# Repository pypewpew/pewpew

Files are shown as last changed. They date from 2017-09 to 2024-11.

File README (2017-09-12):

PewPew Lite FeatherWing is a shield for the Adafruit Feather boards that lets
your easily make simple games with CircuitPython.

* Project page: https://hackaday.io/project/21578-pewpew-featherwing
* Documentation: http://pewpew.readthedocs.io/
* Store: https://www.tindie.com/products/deshipu/pewpew-lite-featherwing/

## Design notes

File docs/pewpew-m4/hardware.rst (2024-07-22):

Hardware
********

Specifications
==============

+---------------------------------------------------------+
| Specification                                           |
+==============+==========================================+
| Display      | 160x128 color TFT                        |
+--------------+------------------------------------------+
| Input        | 7 buttons                                |
+--------------+------------------------------------------+
| Sound        | 7mm buzzer                               |
+--------------+------------------------------------------+
| Interface    | Micro USB                                |
+--------------+------------------------------------------+
| Controller   | SAMD51 ARM Cortex M4                     |
+--------------+------------------------------------------+
| Battery      | 2xAAA 1.5V (not included, optional)      |
+--------------+------------------------------------------+

Open Development
================

This hardware is developed in the open, and all the designs and related
materials are publicly available under a permissive license. You are free
to inspect how it is build, build your own, improve and extend the design,
and even sell your own versions.

The designs are available in the
`project's repository <https://github.com/pypewpew/pewpew-m4-v8>`_.

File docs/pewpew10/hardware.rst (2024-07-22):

Hardware
********

PewPew Standalone v10.2
=======================

PewPew Standalone is a handheld device, it doesn't require any additional
hardware, except for two 1.5V AAA batteries.

+---------------------------------------------------------+
| Specification                                           |
+==============+==========================================+
| Display      | 8×8 red LED matrix                       |
+--------------+------------------------------------------+
| Input        | 6 buttons                                |
+--------------+------------------------------------------+
| Sound        | no sound                                 |
+--------------+------------------------------------------+
| Interface    | 12-pin connector at the back             |
+--------------+------------------------------------------+
| Controller   | Atmel SAMD21                             |
+--------------+------------------------------------------+
| Battery      | 2 x AAA 1.5V alkaline (not included)     |
+--------------+------------------------------------------+

The device includes a display, six buttons, on-off switch, USB port and a
battery holder. The batteries are required for operation, it can't be powered
from the USB port. There is also a 12-pin connector on the back of the device
that can be used for connecting other electronic devices.

.. _12-pin-connector:

The 12-pin Connector
====================

+-------+----------+----------------------------------------------+
| Label | Name     | Function                                     |
+=======+==========+==============================================+
| ``R`` | Reset    | Ground this pin to perform hard reset.       |
+-------+----------+----------------------------------------------+
| ``-`` | GND      | Negative power and ground. There are 2 pins. |
+-------+----------+----------------------------------------------+
| ``1`` | board.P1 | DigitalIO, SWC, SPI-MISO/MOSI, PWM           |
+-------+----------+----------------------------------------------+
| ``2`` | board.P2 | DigitalIO, SWD, SPI-SCK, PWM                 |
+-------+----------+----------------------------------------------+
| ``3`` | board.P3 | DigitalIO, I2C-SDA, SPI-MISO/MOSI, PWM       |
+-------+----------+----------------------------------------------+
| ``4`` | board.P4 | DigitalIO, I2C-SCL, SPI-SCK, PWM             |
+-------+----------+----------------------------------------------+
| ``5`` | board.P5 | DigitalIO, ADC, DAC, PWM, TouchIO            |
+-------+----------+----------------------------------------------+
| ``6`` | board.P6 | DigitalIO, ADC, TouchIO                      |
+-------+----------+----------------------------------------------+
| ``7`` | board.P7 | DigitalIO, SPI-MISO/MOSI, UART, TouchIO      |
+-------+----------+----------------------------------------------+
| ``+`` | VCC      | Positive 3V power. There are 2 pins.         |
+-------+----------+----------------------------------------------+

You can insert a male header into the holes at the back of the device and plug
it into a breadboard to easily gain access to the pins.

Updating the Firmware
=====================

1. Download a ``.uf2`` file from `https://circuitpython.org/board/pewpew10/ <https://circuitpython.org/board/pewpew10/>`_.
2. Connect the PewPew to your computer using a USB cable. It appears as a disk
   named *CIRCUITPY*.
3. Back up all your files, as the update might delete them.
4. "Eject" or "safely remove" the ``CIRCUITPY`` disk.
5. Connect the ``R`` and ``-`` pins on the :ref:`12-pin connector
   <12-pin-connector>` twice in short succession, like a double-click. Seen from
   the front, these are the two rightmost pins. If you added a male pin header,
   this is easily done by touching any metal part to the two pins. The PewPew
   display should go black and a disk named *TRINKETBOOT* should appear.
6. If the *CIRCUITPY* disk reappears instead and the PewPew display shows the
   scrolling menu (or whatever else you installed as ``main.py``), try the
   double-click again, it can take a few tries to get the rhythm right.
7. Copy the downloaded ``.uf2`` file to the *TRINKETBOOT* disk. When it’s done,
   which should take no longer than a few seconds, *TRINKETBOOT* disappears,
   *CIRCUITPY* reappears, and your PewPew is now running the new CircuitPython
   version.
8. If needed, copy all your files back. Also, if you upgraded to a new major
   version, you will need to replace any ``.mpy`` files you have on your device,
   with ones compiled for the new version.

Open Development
================

This hardware is developed in the open, and all the designs and related
materials are publicly available under a permissive license. You are free to
inspect how it is build, build your own, improve and extend the design, and
even sell your own versions.

The designs are available in the
`project's repository <https://github.com/pypewpew>`_.

Buy a Kit
=========

If you want to buy a kit that you only need to solder, you can
find one at `Tindie <https://www.tindie.com/products/deshipu/small-pewpew-standalone/>`_.

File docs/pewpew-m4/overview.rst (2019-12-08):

PewPew M4
*********

PewPew M4 is a CircuitPython graphical handheld game console.

.. toctree::
    :maxdepth: 2

    hardware.rst
    assembly.rst

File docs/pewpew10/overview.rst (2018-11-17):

PewPew 10.2
===========

PewPew 10.2 is a standalone version of the PewPew device, designed specifically
to be cheap and simple to use in workshop settings. You only need two AAA
batteries and a micro-USB cable (with a computer to plug it into) to start
using it.

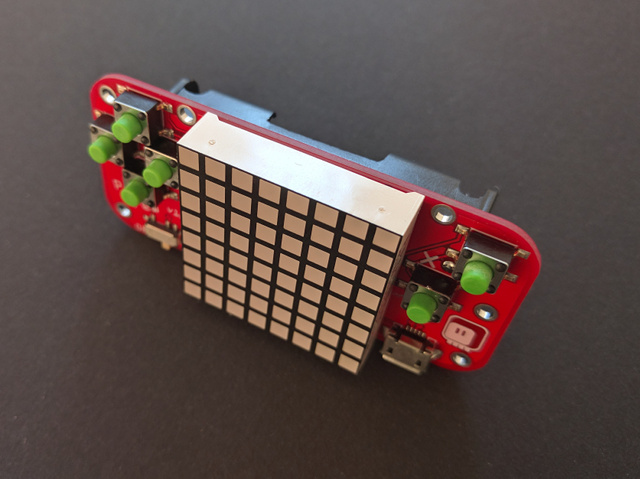
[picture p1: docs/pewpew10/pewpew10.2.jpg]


.. toctree::
    :maxdepth: 2

    hardware.rst
    assembly.rst

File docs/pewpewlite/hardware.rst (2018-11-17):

Hardware
********

PewPew Lite FeatherWing
=======================

PewPew Lite is a shield for the Adafruit Feather series of development boards
(a FeatherWing, as they call them). You put it on top of one of their boards,
and then program that board (preferably in CircuitPython) to create games and
other interactive programs.

+---------------------------------------------------------+
| Specification                                           |
+==============+==========================================+
| Display      | 8×8 4-color LED matrix                   |
+--------------+------------------------------------------+
| Input        | 6 buttons                                |
+--------------+------------------------------------------+
| Sound        | no sound                                 |
+--------------+------------------------------------------+
| Interface    | 2-wire I²C at address 0x70               |
+--------------+------------------------------------------+
| Controller   | Holtek HT16K33                           |
+--------------+------------------------------------------+
| Battery      | Optional 3.7V 100mAh LiPO (not included) |
+--------------+------------------------------------------+

The shield contains six buttons and an eight-by-eight bi-color LED display,
capable of displaying four different colors (black, green, red and yellow). It
also includes a HT16K33 chip that handles the display and the buttons, so that
you can focus on just writing the code for your game. Optionally, you can add a
LiPO battery to it, to make the whole thing into a portable handheld game
console. The shield includes a power switch for that battery.

Open Development
================

This hardware is developed in the open, and all the designs and related
materials are publicly available under a permissive license. You are free
to inspect how it is build, build your own, improve and extend the design,
and even sell your own versions.

The designs are available in the
`project's repository <https://github.com/deshipu/pewpew>`_.

Buy a Kit
=========

If you want to buy a complete kit that doesn't require soldering, you can find
one at `Tindie <https://www.tindie.com/products/deshipu/pewpew-lite-featherwing/>`_.

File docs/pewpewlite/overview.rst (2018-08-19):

PewPew Lite FeatherWing
***********************

PewPew Lite is a FeatherWing that you can use with any of the Adafruit Feather
development boards. It's exactly the size of all FeatherWings, with a green-red
display 2cm on a side, six clicky buttons and a switch for an optional battery.

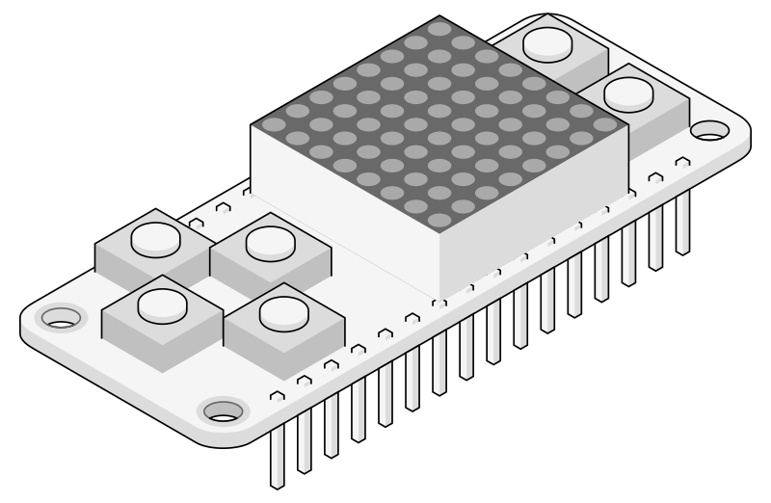
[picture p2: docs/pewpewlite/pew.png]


.. toctree::
    :maxdepth: 2

    hardware.rst
    assembly.rst

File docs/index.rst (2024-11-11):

Welcome to PewPew Documentation
*******************************

PewPew is a family of handheld devices that make learning to write simple
games with Python easy, and also let you tinker with electronics.

They all have a small 8×8 display and six buttons, and they all use the same
"pew" library for accessing them. However, they differ in size, price and
features available.

.. toctree::
    :maxdepth: 2

    pew.rst
    tutorial.rst
    tutorial-sokoban.rst
    tutorial-mine.rst
    pewmulator.rst
    devices.rst
    components.rst
    community.rst

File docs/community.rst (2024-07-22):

Community
*********

If you would like to talk with other users of the device, exchange ideas, seek
help, share the games you made or simply just see what is happening in the
project, you can `subscribe to the mailing list <https://mail.python.org/mailman3/lists/pewpew.python.org/>`_.

There are also some users active at `CircuitPython
Discord <https://discordapp.com/channels/327254708534116352/327298996332658690>`_
channel, if you prefer a more interactive chat.

All the code and design files for the project can be found in the `pewpew-game GitHub repository <https://github.com/pypewpew/>`_.

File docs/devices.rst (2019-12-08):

PewPew Devices
**************

There are several different PewPew devices out there, and a number of further
devices can be made compatible with PewPew by using the right libraries. You
can even build your own device!

.. toctree::
    :maxdepth: 2

    pewpewlite/overview.rst
    pewpew10/overview.rst
    pewpew-m4/overview.rst

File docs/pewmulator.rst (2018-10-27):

Pewmulator
**********

Pewmulator is an emulator for the PewPew library that lets you play the games
writen for the PewPew devices on your computer. It comes in the form of a
Python 3 library that uses PyGame under the hood to implement all necessary
parts of the PewPew library.

Note that the code is then being executed with Python 3 and not CircuitPython,
so there may be some differences. The most obvious difference is the amount of
RAM memory available --- so if you write a game in Pewmulator, chances are it
won't run on PewPew because of lack of memory.

You can get the library from the `github repository
<https://github.com/pewpew-game/pewmulator>`_. Just place the ``pew.py`` file
alongside the code of your game, and run your game with Python 3.

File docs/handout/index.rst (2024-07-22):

:orphan:

.. raw:: latex

   \pagenumbering{gobble}
   \setcounter{secnumdepth}{0}

Handout
=======

.. toctree::
   :maxdepth: 2

   page1header
   ../pew
   page1footer
   ../components/led
   page2footer
   ../components/potentiometer
   page3footer
   ../components/dotstar
   page4footer
   ../components/speaker
   page5footer
   ../components/accelerometer
   page6footer

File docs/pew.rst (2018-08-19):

PewPew Library Reference
************************

.. module:: pew

.. function:: init()

    Initialize the module.

    This function switches the display on and performs some basic setup.

.. function:: brightness(level)

    Set the brightness of the display, from 0 (minimum) to 15 (maximum). On
    devices that don't support varying the brightness this does nothing.

.. function:: show(pix)

    Show the provided image on the display, starting at the top left corner.
    You will want to call this once for every frame.

.. function:: keys()

    Return a number telling which keys (or buttons) have been pressed since the
    last check.  The number can then be filtered with the ``&`` operator and
    the ``K_X``, ``K_DOWN``, ``K_LEFT``, ``K_RIGHT``, ``K_UP``, and ``K_O``
    constants to see whether any of the keys was pressed.

.. function:: tick(delay)

    Wait until ``delay`` seconds have passed since the last call to this
    function. You can call it every frame to ensure a constant frame rate.

.. class:: Pix(width=8, height=8, buffer=None)

    Pix represents a drawing surface, ``width`` pixels wide and ``height``
    pixels high.

    If no ``buffer`` is specified for storing the data, a suitable one will
    be automatically created.

    .. classmethod:: from_iter(cls, lines)

        Creates a new Pix and initialzes its contents by iterating over
        ``lines`` and then over individual pixels in each line. All the lines
        have to be at least as long as the first one.

    .. classmethod:: from_text(cls, text, color=None, background=0, colors=None)

        Creates a new Pix and renders the specified text on it. It is exactly
        the size needed to fit the specified text. Newlines and other control
        characters are rendered as spaces.

        If ``color`` is not specified, it will use yellow and red for the
        letters by default. Otherwise it will use the specified color, with
        ``background`` color as the background.

        Alternatively, ``colors`` may be specified as a 4-tuple of colors,
        and then the ``color`` and ``background`` arguments are ignored, and
        the four specified colors are used for rendering the text.

    .. method:: pixel(self, x, y, color=None)

        If ``color`` is specified, sets the pixel at location ``x``, ``y`` to
        that color. If not, returns the color of the pixel at that location.

        If the location is out of bounds of the drawing surface, returns 0.

    .. method:: box(self, color, x=0, y=0, width=self.width, height=self.height)

        Draws a filled box with the specified ``color`` with its top left
        corner at the specified location and of the specified size. If no
        location and size are specified, fills the whole drawing surface.

    .. method:: blit(self, source, dx=0, dy=0, x=0, y=0, width=None, height=None, key=None)

        Copied the ``source`` drawing surface onto this surface at location
        specified with ``dx`` and ``dy``.

        If ``x``, ``y``, ``widht`` and ``height`` are specified, only copies
        that fragment of the ``source`` image, otherwise copies it whole.

        If ``key`` color is specified, that color is considered transparent
        on the source image, and is not copied onto this drawing surface.

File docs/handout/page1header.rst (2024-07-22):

.. rubric:: Radomir Dopieralski ‹vispew@sheep.art.pl›      Christian Walther ‹cwalther@gmx.ch›

.. rubric:: https://pewpew.rtfd.io

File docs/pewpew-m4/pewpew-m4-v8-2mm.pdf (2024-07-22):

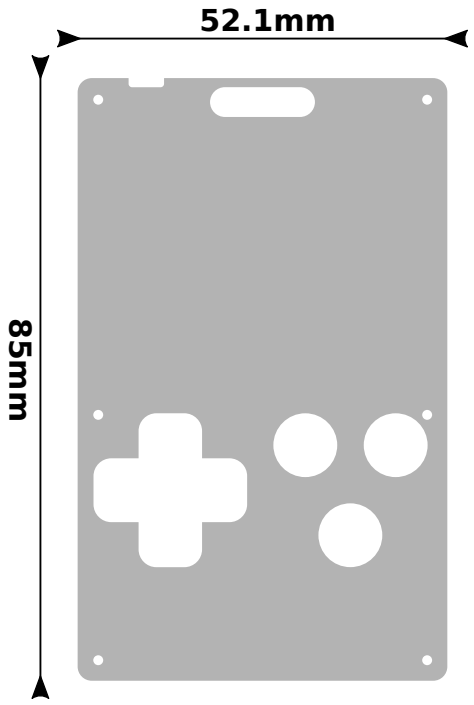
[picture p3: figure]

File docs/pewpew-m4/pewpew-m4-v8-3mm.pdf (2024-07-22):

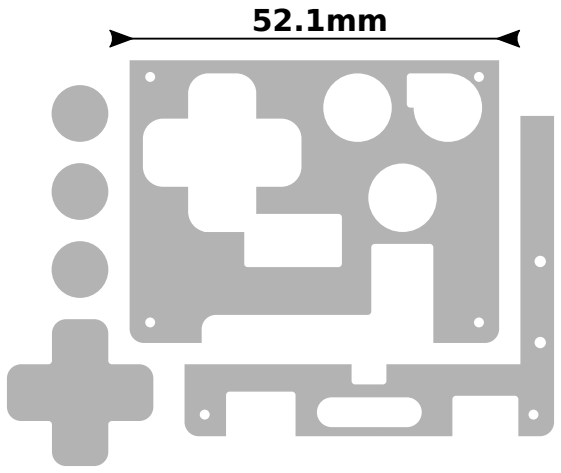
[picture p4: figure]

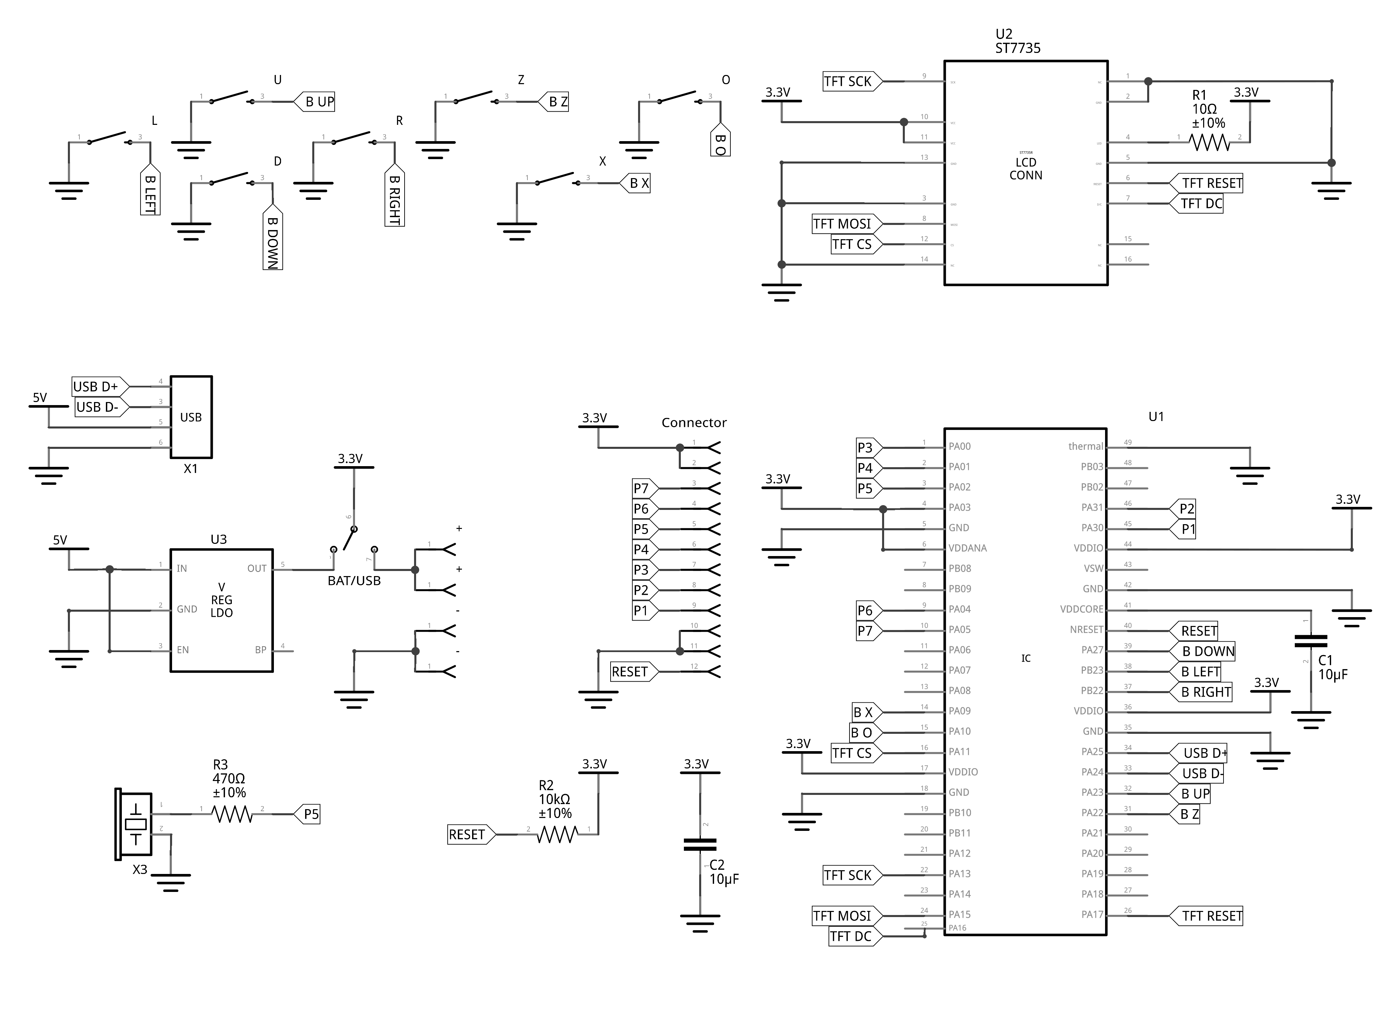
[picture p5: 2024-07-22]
docs/pewpew-m4/pewpew-m4-v8-schematic.png

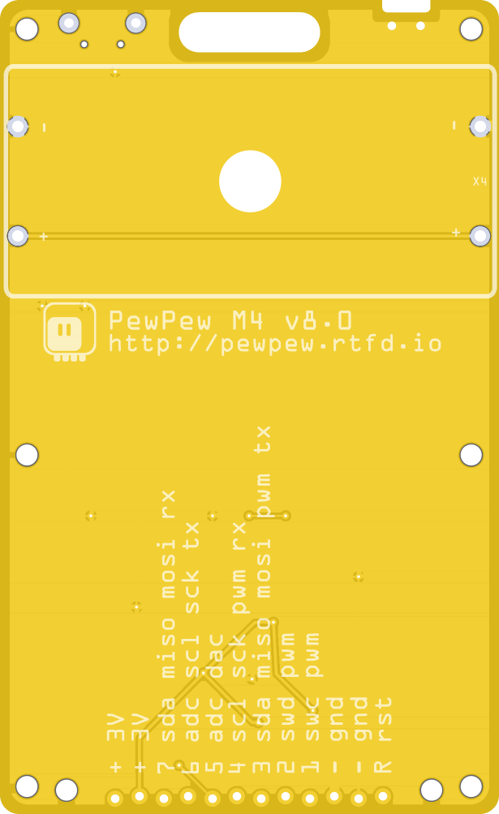
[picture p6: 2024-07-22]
docs/pewpew-m4/pewpew-m4-v8-pcb-bottom.png

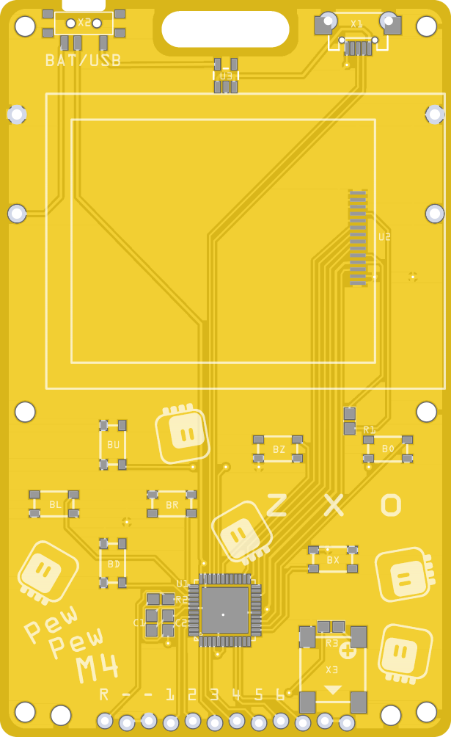
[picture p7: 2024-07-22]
docs/pewpew-m4/pewpew-m4-v8-pcb-top.png

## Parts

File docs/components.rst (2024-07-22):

Connecting Electronics
======================

This section contains some examples to get you started with enhancing your PewPew with various external electronic components.

.. toctree::
   :maxdepth: 2

   components/led
   components/potentiometer
   components/dotstar
   components/speaker
   components/accelerometer

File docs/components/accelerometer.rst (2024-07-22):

Accelerometer
-------------



An accelerometer senses gravity and acceleration using microscopic mechanical parts that are integrated on a silicon chip. It can be used to detect orientation, motion, and gestures like tapping.

The LIS3DH is a low-cost model of accelerometer among many others by different manufacturers. It is a digital device that talks to the microcontroller bidirectionally using a protocol named I²C (*I*\ nter *I*\ ntegrated *C*\ ircuit). I²C uses two signal lines, SDA (*s*\ erial *da*\ ta) and SCL (*s*\ erial *cl*\ ock), plus a common ground. Additionally, I²C requires two resistors (*pull-up resistors*) between each of the signal lines and the positive supply voltage (VCC), this is already done on our LIS3DH breakout board. Multiple devices can be connected to the same I²C bus, the microcontroller can identify them by their address.

To avoid having to remember the raw commands that the microcontroller needs to send over I²C to talk to the accelerometer (they are documented in the `data sheet <https://learn.adafruit.com/adafruit-lis3dh-triple-axis-accelerometer-breakout/downloads>`_ of the part), we use a library that encapsulates that knowledge and abstracts away the specifics of the device. Check the documentation at https://learn.adafruit.com/adafruit-lis3dh-triple-axis-accelerometer-breakout and https://circuitpython.readthedocs.io/projects/lis3dh to learn more about its capabilities, such as tap and double-tap detection. Some of them require additional wiring.

Libraries required: https://github.com/adafruit/Adafruit_CircuitPython_LIS3DH and https://github.com/adafruit/Adafruit_CircuitPython_BusDevice

::

   >>> import board
   >>> import adafruit_lis3dh
   >>> a = adafruit_lis3dh.LIS3DH_I2C(board.I2C(), address=0x1d)
   >>> a.acceleration
   acceleration(x=-0.0862066, y=0.019157, z=9.73177)
   # in m/s^2
   
   >>> import pew
   >>> import math
   >>> pew.init()
   >>> screen = pew.Pix()
   >>> while True:
   ...     x, y, z = a.acceleration
   ...     screen.box(0)
   ...     screen.pixel(4 + math.floor(0.3*x), 3 - math.floor(0.3*y), 3)
   ...     pew.show(screen)
   ...

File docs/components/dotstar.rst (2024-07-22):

Addressable LED Strip
---------------------



These strips can be several meters long and contain hundreds of LEDs, each of them individually controllable. Each of the addressable LED packages contains three LEDs (red, green, blue; some also have a fourth white one) and a controller chip with communication input and output pins. They are daisy-chained on the strip so that the output of one goes to the input of the next. The input of the first one is connected to the microcontroller, which sends out a stream of color values. The first LED takes the first set of them and keeps it for itself, then passes all the rest through to the next one, and so on, until the last LED on the strip only receives the last set of values left for it.

Addressable LEDs exist in two common varieties, “Neopixels” (WS2812B, SK6812), which have one communication line (data), and “Dotstars” (APA102, SK9822), which have two (clock and data). They are all intended for 5 V, but the Dotstars used here happen to work acceptably on 3 V.

Powering 3 addressable LEDs from the PewPew battery or USB supply works, but for longer strips you need a separate power supply (unless you keep very few LEDs on at any time). Each LED can use up to 60 mA (3*20) – multiplied by a large number, this quickly overwhelms small power supplies.

Arrows on the strip indicate the data flow direction – make sure you connect the controller to the input end of the strip. The 5V and GND supply lines run through the whole strip and connect all LEDs in parallel, these can be connected on either end (or even both).

Libraries required: https://github.com/adafruit/Adafruit_CircuitPython_Pixelbuf and https://github.com/adafruit/Adafruit_CircuitPython_Dotstar

::

   >>> import adafruit_dotstar
   >>> import board
   >>> d = adafruit_dotstar.DotStar(board.P2, board.P1, 3, pixel_order=adafruit_dotstar.RBG)
   >>> d
   [[0, 0, 0, 1.0], [0, 0, 0, 1.0], [0, 0, 0, 1.0]]
   # [R (0-255), G (0-255), B (0-255), brightness (0.0-1.0 in steps of 1/31)]
   >>> d[0] = 0x100000
   >>> d[0] = 0x001000
   >>> d[0] = 0x000010
   >>> d[0] = (20, 10, 0)
   >>> d.fill(0)
   >>> import time
   >>> import math
   >>> d.brightness = 0.2
   >>> while True:
   ...     for i in range(3):
   ...         d[i] = [int(255*math.sin(time.monotonic() - 0.5*j + 2.1*i)**12) for j in range(3)]
   ... 
   >>> d.deinit()
   # send raw data using a lower-level interface without the adafruit_dotstar library
   >>> import busio
   >>> spi = busio.SPI(board.P2, MOSI=board.P1)
   >>> spi.try_lock()
   True
   >>> spi.write(b'\x00\x00\x00\x00\xff\x33\x00\x00\xff\x00\x33\x00\xff\x00\x00\x33\xff')
   >>> spi.unlock()
   >>> spi.deinit()

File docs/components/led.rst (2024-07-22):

.. _leds:

Light-Emitting Diodes (LEDs)
----------------------------



.. raw:: latex

   \vspace{4mm}

An LED must be connected in the right orientation: it has a negative lead (cathode) and a positive lead (anode). The cathode is usally marked by being shorter and by a flat part on the rim of the transparent body. Nothing breaks it you insert it the wrong way, it just doesn’t light up.

An LED needs a resistor connected in series, otherwise too much current flows through it and destroys it. It doesn’t matter which way around and on which side of the LED the resistor is placed.

An RGB LED is simply three individual LEDs in the same case, with their cathodes (or anodes) connected together to the longest lead, and the anodes (or cathodes) exposed individually. We use a larger resistance on the green LED because otherwise it is much brighter than the other two, this brings them closer to making white together.

To turn LEDs on and off, we can use any of the PewPew pins as digital outputs.

::

   >>> import board
   >>> import digitalio
   >>> led = digitalio.DigitalInOut(board.P1)
   >>> led.direction = digitalio.Direction.OUTPUT
   >>> led.value = 1
   >>> led.value = 0

Pulse-Width Modulation (PWM)
----------------------------

To dim an LED, we can make use of the microcontroller’s ability to blink an output very quickly, with a fixed frequency, but a variable duration of the “on” part of the period. This is called *pulse-width modulation* (PWM) and is easier for a microcontroller to do than outputting a continuously variable voltage. The ratio of the “on” part to the whole period is called *duty cycle* and is specified as an integer from 0 (always off) to 65535 (always on).

::

   >>> import board
   >>> import pwmio
   >>> r = pwmio.PWMOut(board.P1)
   >>> g = pwmio.PWMOut(board.P3)
   >>> b = pwmio.PWMOut(board.P4)
   >>> r.duty_cycle = 0
   >>> r.duty_cycle = 100
   >>> r.duty_cycle = 10000
   >>> r.duty_cycle = 65535
   >>> import time
   >>> import math
   >>> while True:
   ...     r.duty_cycle = int(65535*(0.5 + 0.5*math.sin(time.monotonic())))
   ...     g.duty_cycle = int(65535*(0.5 + 0.5*math.sin(time.monotonic() - 2.1)))
   ...     b.duty_cycle = int(65535*(0.5 + 0.5*math.sin(time.monotonic() - 4.2)))
   ... 
   #   ^ delete the indenting spaces and press return to end the block
   # press ctrl-C to exit from the infinite loop

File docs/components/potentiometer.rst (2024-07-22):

Potentiometer
-------------



A potentiometer is an adjustable resistor. As its schematic symbol illustrates, it consists of a track of resistive material on which a wiper can slide. The left and right end of the track are connected to the outer pins of the part, the wiper to the middle pin. When the wiper is moved to the left end, the resistance between the left and middle pins is approximately zero. As the wiper is moved to the right, it continuously increases until it reaches the full value when the wiper is at the right end. Conversely, the resistance between the middle and right pins decreases.

When the left and right ends of the track are connected to ground (0V) and +3V (which makes a small current flow through it), the potentiometer acts as a variable *voltage divider*: the middle pin smoothly moves from 0V to 3V as the wiper is moved from left to right.

We can measure this voltage using an analog-to-digital converter (ADC) contained in the microcontroller. On the PewPew, ADCs are available on pins 5, 6, and 7. They linearly convert a voltage between zero and the full supply voltage into an integer between 0 and 65535.

An analog joystick is a combination of two potentiometers.

Light-Dependent Resistor (LDR)
------------------------------



The resistance of an LDR decreases when light shines onto it.

We can combine it to a voltage divider with a fixed resistor and measure the resulting variable voltage using an ADC.

.. raw:: latex

   ~\\ \\

::

   >>> import board
   >>> import analogio
   >>> adc = analogio.AnalogIn(board.P5)
   # potentiometer turned to the left
   >>> adc.value
   48
   # potentiometer turned to the right
   >>> adc.value
   65520
   >>> import pew
   >>> pew.init()
   >>> screen = pew.Pix()
   >>> while True:
   ...     screen.blit(screen, 0, 0, 1, 0, 7, 8)
   ...     screen.box(0, 7, 0, 1, 8)
   ...     screen.pixel(7, 7 - (adc.value >> 13), 3)
   ...     pew.show(screen)
   ...     pew.tick(0.1)
   ... 
   #   ^ delete the indenting spaces and press return to end the block
   # press ctrl-C to exit from the infinite loop

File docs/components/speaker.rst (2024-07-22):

Piezo Speaker
-------------



A piezo speaker (also called *passive buzzer*) converts electricity into sound using a crystal that expands and contracts when placed in an electric field. It is not suitable for high-quality music, but good for simple beeps, and uses very little power. It doesn’t matter which way you connect it.

The PewPew 10 lacks most of the advanced sound generation capabilities of CircuitPython because they didn’t fit in the small flash memory of the microcontroller, but we can generate simple square waves using the pulse-width modulation facility (described on the :ref:`leds` page).

(There is a digital-to-analog converter (DAC) on pin 5 that can be used with the ``analogio`` module, but feeding it new values regularly enough for sound is hard without support from the firmware.)

.. raw:: latex

   ~\\

::

   >>> import board
   >>> import pwmio
   >>> p = pwmio.PWMOut(board.P4, variable_frequency=True)
   >>> p.duty_cycle = 32768
   # initial frequency is 500 Hz
   >>> p.frequency = 250
   >>> p.frequency = 1000
   >>> p.duty_cycle = 0

   >>> import time
   >>> def play(tune):
   ...     p.duty_cycle = 32768
   ...     for f, d in tune:
   ...         p.frequency = f
   ...         time.sleep(d)
   ...     p.duty_cycle = 0
   ... 
   >>> play(((440, 0.2), (550, 0.1), (587, 0.1), (660, 0.1)))

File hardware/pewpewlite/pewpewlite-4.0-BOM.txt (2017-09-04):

8x8 1.9mm common-cathode bi-color matrix 788AHG     $1.50   1x  $1.50
HT16K33 28SOP                                       $0.60   1x  $0.60
39kΩ 0805 resistor                                  $0.004  6x  $0.024
4.7kΩ 0805 resistor                                 $0.004  2x  $0.008
SPDT slide switch MK12C02                           $0.10   1x  $0.10
Tact switch 6x6x4.5mm                               $0.02   6x  $0.12
2.54mm male pin header                              $0.05   1x  $0.05
Custom PCB 50.6x22.7mm                              $1.00   1x  $1.00
Solder, flux, etc.                                  $0.168  1x  $0.168
----------------------------------------------------------------------
                                                        Total:  $3.50

Note: prices are for a batch of 10 pieces.

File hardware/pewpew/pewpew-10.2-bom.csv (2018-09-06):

Part/Designator | Manufacture Part Number/Description | Quantity | Remarks/Links
U1 | ATSAMD21E18A-MU | 1 | microcontroller: https://www.mouser.ch/ProductDetail/556-ATSAMD21E18A-MU
C1,C2 | 1uF 0805 capacitor | 2
ON/OFF | MK12C02 | 1 | switch: https://www.aliexpress.com/item/10PCS-Lot-MP3-Toggle-Switch-MK12C02-7P-12608-Micro-Switch-Miniature-Toggle-MP3-Key-Button/32812362709.html
X2 | 10118193-0001LF | 1 | microusb socket: https://www.aliexpress.com/item/20PCS-LOT-MicroUSB-socket-MK5P-Mike-5P-MINIUSB-USB-5-pin-female/32874709816.html
O,X,up,down,left,right | SMD Tact Switch 6*6*6mm Green | 6 | https://www.aliexpress.com/item/4-Pins-SMT-Mini-Hand-Touch-Switch-SMD-Tact-Switch-6-6-6mm-White-Green-Orange/32698050818.html
X1 | 1088BS 8x8 Red 3mm Square LED Matrix | 1 | Leave unsoldered, https://www.aliexpress.com/item/FREE-SHIPPING-10PCS-x-3MM-8X8-RED-32-32mm-Square-LED-Dot-Matrix-Digital-Tube-Module/32756487745.html
+/- | 2xAAA battery holder | 1 | Leave unsoldered, https://www.aliexpress.com/item/7Pcs-Black-Red-2-Wire-Cable-Connectors-2x-AAA-Battery-Box-Case-Holder/32871718687.html

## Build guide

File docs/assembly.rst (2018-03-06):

Assembly and Setup
******************

The PewPew FeatherWing comes without the pin headers and LED matrix attached,
so that some simple soldering is required before using it.

Basic Assembly
==============

The simplest way to assemble the PewPew board is to use an `Adafruit Feather
<https://www.adafruit.com/category/946>`_ board that supports CircuitPython (the
`Feather M0 Express <https://www.adafruit.com/product/3403>`_ works great for
this) with female pin headers, and to solder the male pin headers onto the
PewPew FeatherWing. Afterwards, insert the LED Matrix into place, solder its
pins from the bottom, and trim them with wire cutters.

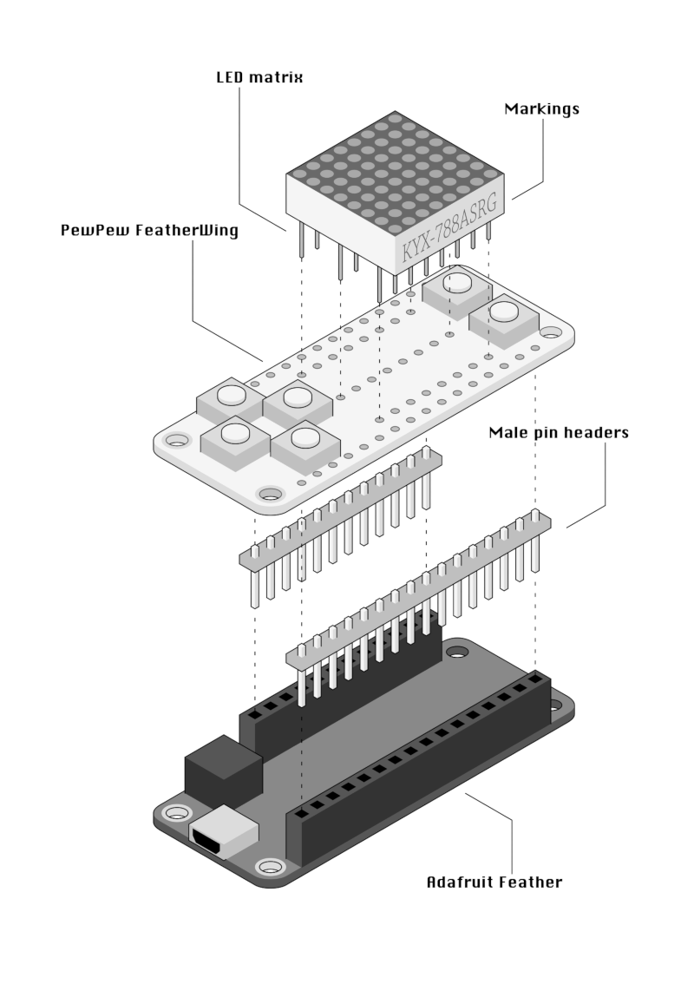
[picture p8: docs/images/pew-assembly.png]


Make sure to insert the LED Matrix in correct orientation -- with the markings
in the same direction as the "down" button. Otherwise the colors will be wrong,
and the image will be flipped.

Note that you should solder the pin headers first, and then solder the LED
matrix. Trying to do it in the opposite order may lead to damaging the matrix
with your soldering iron.

.. note:: The Adafruit Feather board is not included in the kit.

Making it Flatter
=================

The basic assembly is fine, but it's good 2cm thick. You can make the whole
thing much thinner by applying a number of tricks. First, use the `short female
pin headers <https://www.adafruit.com/product/2940>`_ for the Adafruit Feather.
Second, move the plastic on your male pin headers to the end of the header,
insert the header from the top, and try it with the Feather to see how long the
pins need to be. Then solder them, and trim the parts sticking out from the top
with wire cutters. This way the PewPew FeatherWing can sit right on top of the
battery plug of the Feather.

.. note:: Note that the short female headers are not included in the kit.

Optional Battery
================

To make the PewPew even more portable, you can add a small LiPO battery (`the
100mAh batteries <https://www.adafruit.com/product/1570>`_ are about the right
size). The FeatherWing even has a power switch built-in that you can use. Just
solder the battery leads to the two holes marked "+" for the red wire, and "-"
for the black wire. Be very careful to not short the battery wires while you
are doing that. Then you can use two-sided tape to stick the battery on the
underside of the FeatherWing, sandwiching it between the two boards. You may
need to add some electric tape to prevent the metal body of the battery from
shorting things on the boards.

.. note:: Note that the battery is not included in the kit.

Software Setup
==============

All the example programs are written using CircuitPython, so you will need to
get that running on your Feather board. Fortunately Adafruit provides a lot of
tutorials about how to do it. Some of the boards (like the M0 Express) even
come with CircuitPython already loaded on them. Please see
 `this guide <https://learn.adafruit.com/welcome-to-circuitpython/installing-circuitpython>`_.

Once you have CircuitPython running on the board, you need to copy the
``pew.mpy`` file to it. That's the main library that contains all the functions
needed to use the PewPew hardware.

In addition, you need to copy your program onto the board. You have to name it
``main.py`` for it to be started automatically on power-up. Later on we will
see how we can use a menu program that will let you choose what to run (you
have to rename the ``menu.py`` to ``main.py`` to have it run at start).

You can get all the files from the `project's repository
<https://github.com/deshipu/pewpew>`_, and the compiled files are available
from the `releases page <https://github.com/pewpew-game/pewpew/releases>`_.

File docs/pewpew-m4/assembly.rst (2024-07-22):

Assembly and Setup
******************

Electronics
===========

If you bought a kit, you will receive this part already assembled and programmed.

Schematic
---------

This is the schematic of the device.



Printed Circuit Board
---------------------

A printed circuit board is necessary for assembling the electronic part of the
console. You can find the gerber files in the project's repository.





If you need to make modifications to the PCB designs, the Fritzing file is also
available in the project's repository.

Bill of Materials
-----------------

You will need the following components:

+--------------------+-----------------------------------+--------+---------------------------------------------------------------------------------+
|Part/Designator     |Manufacture Part Number/Description|Quantity|Remarks/Links                                                                    |
+====================+===================================+========+=================================================================================+
|U1                  |ATSAMD51G19A-MU                    |1       |`Mouser <https://www.mouser.ch/ProductDetail/556-ATSAMD51G19AMU>`_               |
+--------------------+-----------------------------------+--------+---------------------------------------------------------------------------------+
|U2                  |ST7735R 1.8inch TFT                |1       |https://www.aliexpress.com/item/32818686437.html                                 |
+--------------------+-----------------------------------+--------+---------------------------------------------------------------------------------+
|U3                  |AP2112K-3.3TRG1 ldo                |1       |                                                                                 |
+--------------------+-----------------------------------+--------+---------------------------------------------------------------------------------+
|C1 C2               |10uF 0805 capacitor 3V             |2       |                                                                                 |
+--------------------+-----------------------------------+--------+---------------------------------------------------------------------------------+
|R1                  |10Ohm 0805 resistor                |1       |                                                                                 |
+--------------------+-----------------------------------+--------+---------------------------------------------------------------------------------+
|R2                  |10kOhm 0805 resistor               |1       |                                                                                 |
+--------------------+-----------------------------------+--------+---------------------------------------------------------------------------------+
|R3                  |470Ohm 0805 resistor               |1       |                                                                                 |
+--------------------+-----------------------------------+--------+---------------------------------------------------------------------------------+
|X1                  |10118193-0001LF microusb socket    |1       |https://www.aliexpress.com/item/32874709816.html                                 |
+--------------------+-----------------------------------+--------+---------------------------------------------------------------------------------+
|X2                  |MK12C02 switch                     |1       |https://www.aliexpress.com/item/32812362709.html                                 |
+--------------------+-----------------------------------+--------+---------------------------------------------------------------------------------+
|X3                  |HYG7525                            |1       |https://www.aliexpress.com/item/1707004675.html                                  |
+--------------------+-----------------------------------+--------+---------------------------------------------------------------------------------+
|X4                  |2xAAA battery holder               |1       |https://www.aliexpress.com/item/32921198766.html                                 |
+--------------------+-----------------------------------+--------+---------------------------------------------------------------------------------+
|BU BD BL BR BZ BX BO|SKRPABE010 switch 1.57N            |7       |https://www.aliexpress.com/item/4000424101435.html                               |
+--------------------+-----------------------------------+--------+---------------------------------------------------------------------------------+
|                    |two-sided tape                     |1.5cm   |for attaching the battery holder https://www.aliexpress.com/item/33030272723.html|
+--------------------+-----------------------------------+--------+---------------------------------------------------------------------------------+

The positions of the components are marked on the PCB's silkscreen, and there
is also a pick-and-place file included with the gerbers.

Please make sure to use the correct set of holes for the battery holder,
depending on the polarity of the particular model you have. If you need to use
the holes on the side of the display connector, it's best to solder the battery
holder first, and the display later.

Bootloader
----------

You will find the UF2 bootloader binary and sources in the project's
repository.  In order to flash it to the chip on the PCB, you will need an
SWD-capable programmer, such as JLink.

Connect your programmer to the 12-pin connector at the bottom as follows:

+----------+------+
|Programmer|Device|
+==========+======+
|SWDCLK    | 1    |
+----------+------+
|SWDIO     | 2    |
+----------+------+
|RST       | R    |
+----------+------+
|VCC       | ``+``|
+----------+------+
|GND       | ``-``|
+----------+------+

While programming, the device needs to be powered either from battery, from
USB, or with 3.3V through the ``+`` and ``-`` pins.

If programming from the command line, use the following commands::

    JLinkExe -if SWD -device ATSAMD51G19A -speed 4000kHz
    J-Link> connect
    J-Link> erase
    J-Link> loadbin pewpew-m4-v8-bootloader.bin 0
    J-Link> g
    J-Link> qc

After this, a ``PEWBOOT`` disk should become visible over USB. The UF2 files
can be copied to that disk to flash them on the device.  To force the device
into a bootloader mode again, the ``R`` pin needs to be shorted with the ``-``
twice.

Firmware
--------

The CircuitPython firmware can be downloaded form the `official CircuitPython
downloads page <http://circuitpython.org/downloads>`_. The UF2 file just needs
to be copied over USB to the ``PEWBOOT`` disk.

Case
====

The case consists of two layers of acrylic parts, held together with six
screws, and four button caps, attached to the switches with pieces of two-sided
tape or glue. The whole assembly is shown below.



Acrylic Layers
--------------

The acrylic parts are laser-cut from 2mm clear and 3mm translucent sheets.





It's possible to cut more than one set of parts from a single sheet, so you may
want to modify the provided designs. Please also note that the design files
include dimensions, which should be ignored by the cutter.

Bill of Materials
------------------

+-------------------------------------+--------+------------------------------------------------+
|Description                          |Quantity|Remarks/Links                                   |
+=====================================+========+================================================+
|M1.8 6mm flat-head self-tapping screw|6       |https://www.aliexpress.com/item/32976344389.html|
+-------------------------------------+--------+------------------------------------------------+
|2mm clear transparent acrylic parts  |1       |see pewpew-m4-v8-2mm.svg                        |
+-------------------------------------+--------+------------------------------------------------+
|3mm orange translucent acrylic parts |1       |see pewpew-m4-v8-3mm.svg                        |
+-------------------------------------+--------+------------------------------------------------+

Project Reposiotory
===================

All the design files can be found in the `project's repository
<https://github.com/pewpew-game/pewpew-m4-v8>`_.

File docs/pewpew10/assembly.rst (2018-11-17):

Assembly
********

Unless you are participating in a workshop, the device comes unassembled. There
are three parts: the printed circuit board with the buttons and the
electronics, the display, and the battery holder. To assemble it you will need
a soldering iron, wire cutters, solder and two-sided tape. You will also need
two AAA 1.5V batteries, a micro-USB cable and a computer with a working USB
port.

Display
-------

You start the assembly by attaching and soldering the display. Insert the
provided LED matrix into the 16 holes in the middle of the printed circuit
board, making sure that the side of the matrix with text on it faces right,
towards the two fire buttons. You may need to straighten the pins a little if
they bent during the transport.

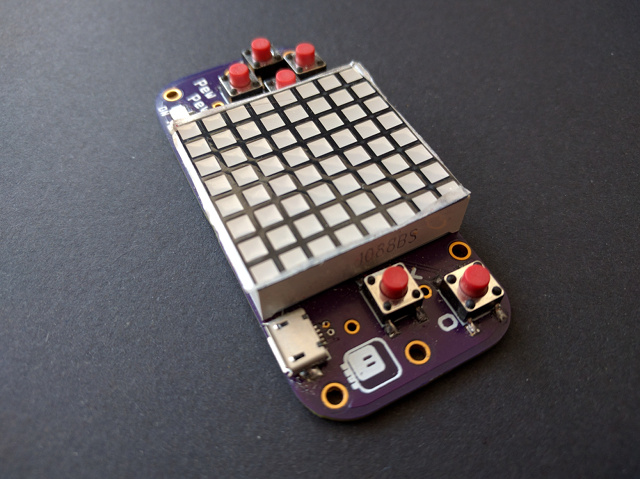
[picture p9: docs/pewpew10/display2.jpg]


.. warning:: If you solder the display in the wrong orientation, it will not
    work correctly. Please make sure the orientation is correct before you
    start soldering.

Once the matrix is inserted, flip the device up-side-down, make sure that the
display aligns flush with the sides (there is a little wiggle room), and solder
each of the pins. To do that, touch the tip of a hot soldering iron to the pin
and the ring around the hole at the same time, wait a second for them to become
hot, and then touch them with the solder wire, melting enough solder to fill
the hole.

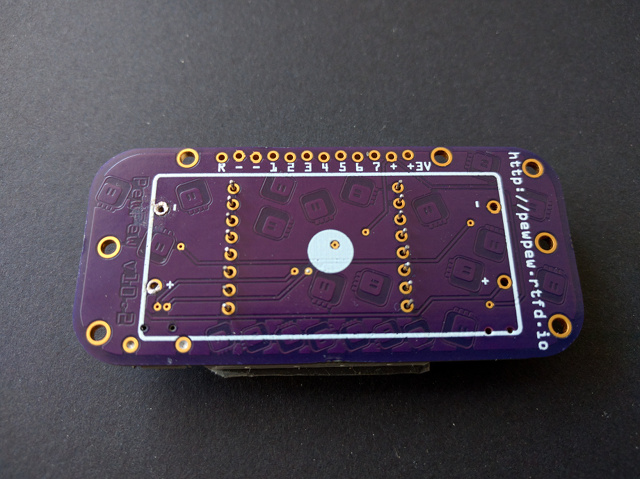
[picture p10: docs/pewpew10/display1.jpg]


.. note:: If you are new to soldering, you can find soldering tutorials on the
    Internet.

Once all 16 pins of the matrix are soldered, use the wire cutters to cut them
flush with the circuit board.

Battery
-------

The next step is connecting and attaching the battery holder. First, make sure
that the wires of the battery holder go through the holes in the plastic that
are furthest apart. If they go through the holes that are close together, you
will need to move them back, and thread them through the correct holes. Once
you have done that, cut both wires to about 1cm length and remove the
insulation from them with the wire cutters (please don't use your teeth). Twist
the strands of each of the wire, so that they are easier to move through the
holes in the circuit board. Next, place two-sided tape on the battery holder,
and attach it to the circuit board so that the two wires go through the holes
marked + and - (make sure the red wire goes to +, and the black one to -).
There are two sets of such holes, pick the correct one depending on what order
the wires come out of your battery holder.

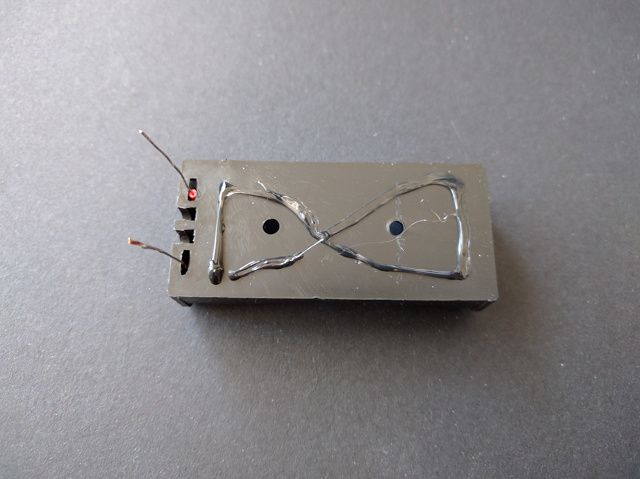
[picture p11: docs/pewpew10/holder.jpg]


.. warning:: It is very important to pay attention to the battery polarity, as
    this device doesn't have any kind of reverse polarity protection, and
    coonnecting the batteries in reverse will damage it.

Flip the device to the top side, and use the soldering iron to solder the two
wires sticking out of the holes in the circuit board. Be careful to not touch
the plastic of the buttons with your iron, as it will melt. Finally, cut the
excess wires with your wire cutters. Your device is ready.

Insert two AAA 1.5V batteries into the battery holder, switch it on, and you
should see text "snake" scrolling on the display.

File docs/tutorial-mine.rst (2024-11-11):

Mine Tutorial
*************

We will make a game inspired by titles such as Dig Dug and Boulder Dash, where
the player controls a miner, who digs tunnel in a mine filled with boulders and
treasure. The goal is to collect all the treasure without being crushed by a
boulder.

We will start with creating and displaying the map of the mine:

.. code-block:: python

    import pew

    pew.init()
    world = pew.Pix.from_iter([
        [1, 1, 1, 1, 1, 1, 1, 1],
        [1, 1, 1, 1, 1, 1, 1, 1],
        [1, 1, 2, 1, 2, 1, 1, 1],
        [1, 1, 2, 1, 3, 1, 1, 1],
        [1, 1, 1, 1, 1, 1, 2, 1],
        [1, 1, 1, 1, 1, 2, 3, 2],
        [1, 3, 1, 1, 1, 1, 2, 1],
        [1, 1, 1, 1, 1, 1, 1, 1],
    ])
    delay = 1/6
    end = False

    while not end:
        pew.show(world)
        pew.tick(delay)

In the above code, we initialize the ``pew`` library, create a bitmap
to hold the map of the world, and then, in an infinite loop, display it
and wait for the next frame.

Next we want to display the miner:

.. code-block:: python
    :emphasize-lines: 15-17,23,26

    import pew

    pew.init()
    world = pew.Pix.from_iter([
        [1, 1, 1, 1, 1, 1, 1, 1],
        [1, 1, 1, 1, 1, 1, 1, 1],
        [1, 1, 2, 1, 2, 1, 1, 1],
        [1, 1, 2, 1, 3, 1, 1, 1],
        [1, 1, 1, 1, 1, 1, 2, 1],
        [1, 1, 1, 1, 1, 2, 3, 2],
        [1, 3, 1, 1, 1, 1, 2, 1],
        [1, 1, 1, 1, 1, 1, 1, 1],
    ])
    x = 0
    y = 0
    blink = True
    delay = 1/6
    end = False

    while not end:
        world.pixel(x, y, 3 if blink else 0)
        pew.show(world)
        pew.tick(delay)
        blink = not blink

We define global variables ``x`` and ``y`` to hold the position of the
miner, and ``blink`` to track what color we should display. Then we
just color the pixel at that position depending on the state of
``blink``, and flip it to the other state.

Next, we will let the player move the miner:

.. code-block:: python
    :emphasize-lines: 23-42

    import pew

    pew.init()
    world = pew.Pix.from_iter([
        [1, 1, 1, 1, 1, 1, 1, 1],
        [1, 1, 1, 1, 1, 1, 1, 1],
        [1, 1, 2, 1, 2, 1, 1, 1],
        [1, 1, 2, 1, 3, 1, 1, 1],
        [1, 1, 1, 1, 1, 1, 2, 1],
        [1, 1, 1, 1, 1, 2, 3, 2],
        [1, 3, 1, 1, 1, 1, 2, 1],
        [1, 1, 1, 1, 1, 1, 1, 1],
    ])
    x = 0
    y = 0
    blink = True
    delay = 1/6
    end = False

    while not end:
        world.pixel(x, y, 4)
        buttons = pew.keys()
        while pew.keys():
            pew.tick(delay)
        dx = 0
        dy = 0
        if buttons & pew.K_UP:
            dy = -1
        elif buttons & pew.K_DOWN:
            dy = 1
        elif buttons & pew.K_LEFT:
            dx = -1
        elif buttons & pew.K_RIGHT:
            dx = 1
        if (0 <= x + dx <= 7 and 0 <= y + dy <= 7 and
                world.pixel(x + dx, y + dy) != 2):
            world.pixel(x, y, 0)
            x += dx
            y += dy
            world.pixel(x, y, 4)
        world.pixel(x, y, 3 if blink else 0)
        pew.show(world)
        pew.tick(delay)
        blink = not blink

We will paint the position of the miner with a non-existng color 4
temporarily, so that it will be easier for us later to check various
conditions. Later we overwrite it with the blinking color anyways, so
this is never visible.

Then we read the state of the buttons, wait for all buttons to be released,
and figure out the direction in which we want to move depending on which
buttons are pressed.

Then we check if the movement wouldn't take us outside the screen, horizontally and vertically, and if there isn't a boulder in the way. If everything is fine, we draw a tunnel where the miner was, and move them to the new position.

Next, we will add pushing of boulders:

.. code-block:: python
    :emphasize-lines: 43-49

    import pew

    pew.init()
    world = pew.Pix.from_iter([
        [1, 1, 1, 1, 1, 1, 1, 1],
        [1, 1, 1, 1, 1, 1, 1, 1],
        [1, 1, 2, 1, 2, 1, 1, 1],
        [1, 1, 2, 1, 3, 1, 1, 1],
        [1, 1, 1, 1, 1, 1, 2, 1],
        [1, 1, 1, 1, 1, 2, 3, 2],
        [1, 3, 1, 1, 1, 1, 2, 1],
        [1, 1, 1, 1, 1, 1, 1, 1],
    ])
    x = 0
    y = 0
    blink = True
    delay = 1/6
    end = False

    while not end:
        world.pixel(x, y, 4)
        buttons = pew.keys()
        while pew.keys():
            pew.tick(delay)
        dx = 0
        dy = 0
        if buttons & pew.K_UP:
            dy = -1
        elif buttons & pew.K_DOWN:
            dy = 1
        elif buttons & pew.K_LEFT:
            dx = -1
        elif buttons & pew.K_RIGHT:
            dx = 1
        if (0 <= x + dx <= 7 and 0 <= y + dy <= 7 and
                world.pixel(x + dx, y + dy) != 2):
            world.pixel(x, y, 0)
            x += dx
            y += dy
            world.pixel(x, y, 4)
        elif (dy == 0 and 1 <= x + dx <= 6 and
                world.pixel(x + 2 * dx, y + 2 * dy) == 0):
            world.pixel(x, y, 0)
            x += dx
            y += dy
            world.pixel(x, y, 4)
            world.pixel(x + dx, y + dy, 2)
        world.pixel(x, y, 3 if blink else 0)
        pew.show(world)
        pew.tick(delay)
        blink = not blink

We check that the movement is horizontal, that we are not pushing the boulder
outside the screen, and that there is an empty space behind the boulder. Then
we move both the miner and the boulder.

Finally, we need to add gravity for the boulders, so that they fall down when
there is nothing under them.

.. code-block:: python
    :emphasize-lines: 50-57

    import pew

    pew.init()
    world = pew.Pix.from_iter([
        [1, 1, 1, 1, 1, 1, 1, 1],
        [1, 1, 1, 1, 1, 1, 1, 1],
        [1, 1, 2, 1, 2, 1, 1, 1],
        [1, 1, 2, 1, 3, 1, 1, 1],
        [1, 1, 1, 1, 1, 1, 2, 1],
        [1, 1, 1, 1, 1, 2, 3, 2],
        [1, 3, 1, 1, 1, 1, 2, 1],
        [1, 1, 1, 1, 1, 1, 1, 1],
    ])
    x = 0
    y = 0
    blink = True
    delay = 1/6
    end = False

    while not end:
        world.pixel(x, y, 4)
        buttons = pew.keys()
        while pew.keys():
            pew.tick(delay)
        dx = 0
        dy = 0
        if buttons & pew.K_UP:
            dy = -1
        elif buttons & pew.K_DOWN:
            dy = 1
        elif buttons & pew.K_LEFT:
            dx = -1
        elif buttons & pew.K_RIGHT:
            dx = 1
        if (0 <= x + dx <= 7 and 0 <= y + dy <= 7 and
                world.pixel(x + dx, y + dy) != 2):
            world.pixel(x, y, 0)
            x += dx
            y += dy
            world.pixel(x, y, 4)
        elif (dy == 0 and 1 <= x + dx <= 6 and
                world.pixel(x + 2 * dx, y + 2 * dy) == 0):
            world.pixel(x, y, 0)
            x += dx
            y += dy
            world.pixel(x, y, 4)
            world.pixel(x + dx, y + dy, 2)
        for row in range(7, -1, -1):
            for col in range(8):
                if world.pixel(col, row) == 2:
                    if world.pixel(col, row + 1) == 0:
                        world.pixel(col, row, 0)
                        world.pixel(col, row + 1, 2)
                        if world.pixel(col, row + 2) == 4:
                            end = True
        world.pixel(x, y, 3 if blink else 0)
        pew.show(world)
        pew.tick(delay)
        blink = not blink

    import supervisor
    supervisor.reload()

We iterate over the whole world map, starting from the bottom row-by-row, and going up. Every time we find a boulder, we check if there is an empty space under it. If there is, we move it into that empty space. Since we are going from the bottom up, we will only do this once every frame, so we can see the boulder falling gradually down when there is more space below it.

In addition, if we hit the miner while falling, we end the game by setting the ``end`` variable to ``True``. We added a reload at the end of the program, to make sure we can play the game from the beginning.

But boulders only falling down is not that interesting, we also want them to slip sideways if they stand on other boulders and there is empty space on the side.

.. code-block:: python
    :emphasize-lines: 58-66

    import pew

    pew.init()
    world = pew.Pix.from_iter([
        [1, 1, 1, 1, 1, 1, 1, 1],
        [1, 1, 1, 1, 1, 1, 1, 1],
        [1, 1, 2, 1, 2, 1, 1, 1],
        [1, 1, 2, 1, 3, 1, 1, 1],
        [1, 1, 1, 1, 1, 1, 2, 1],
        [1, 1, 1, 1, 1, 2, 3, 2],
        [1, 3, 1, 1, 1, 1, 2, 1],
        [1, 1, 1, 1, 1, 1, 1, 1],
    ])
    x = 0
    y = 0
    blink = True
    delay = 1/6
    end = False

    while not end:
        world.pixel(x, y, 4)
        buttons = pew.keys()
        while pew.keys():
            pew.tick(delay)
        dx = 0
        dy = 0
        if buttons & pew.K_UP:
            dy = -1
        elif buttons & pew.K_DOWN:
            dy = 1
        elif buttons & pew.K_LEFT:
            dx = -1
        elif buttons & pew.K_RIGHT:
            dx = 1
        if (0 <= x + dx <= 7 and 0 <= y + dy <= 7 and
                world.pixel(x + dx, y + dy) != 2):
            world.pixel(x, y, 0)
            x += dx
            y += dy
            world.pixel(x, y, 4)
        elif (dy == 0 and 1 <= x + dx <= 6 and
                world.pixel(x + 2 * dx, y + 2 * dy) == 0):
            world.pixel(x, y, 0)
            x += dx
            y += dy
            world.pixel(x, y, 4)
            world.pixel(x + dx, y + dy, 2)
        for row in range(7, -1, -1):
            for col in range(8):
                if world.pixel(col, row) == 2:
                    if world.pixel(col, row + 1) == 0:
                        world.pixel(col, row, 0)
                        world.pixel(col, row + 1, 2)
                        if world.pixel(col, row + 2) == 4:
                            end = True
                    elif world.pixel(col, row + 1) in {2, 3}:
                        if (world.pixel(col + 1, row) == 0 and
                           world.pixel(col + 1, row + 1) == 0):
                                world.pixel(col, row, 0)
                                world.pixel(col + 1, row, 2)
                        elif (world.pixel(col - 1, row) == 0 and
                           world.pixel(col - 1, row + 1) == 0):
                                world.pixel(col, row, 0)
                                world.pixel(col - 1, row, 2)
        world.pixel(x, y, 3 if blink else 0)
        pew.show(world)
        pew.tick(delay)
        blink = not blink

    import supervisor
    supervisor.reload()

If there is no empty space below a boulder, we check if it's another boulder
or treasure. If it is, we check the two spaces to the left and to the right -- if they are empty, we can move the boulder sideways, and it will fall down in the next frame.

Finally, we need a winning condition. We need to count how many treasures are there left on the map, and end the game when there are none.

.. code-block:: python
    :emphasize-lines: 50,53-55,70-71

    import pew

    pew.init()
    world = pew.Pix.from_iter([
        [1, 1, 1, 1, 1, 1, 1, 1],
        [1, 1, 1, 1, 1, 1, 1, 1],
        [1, 1, 2, 1, 2, 1, 1, 1],
        [1, 1, 2, 1, 3, 1, 1, 1],
        [1, 1, 1, 1, 1, 1, 2, 1],
        [1, 1, 1, 1, 1, 2, 3, 2],
        [1, 3, 1, 1, 1, 1, 2, 1],
        [1, 1, 1, 1, 1, 1, 1, 1],
    ])
    x = 0
    y = 0
    blink = True
    delay = 1/6
    end = False

    while not end:
        world.pixel(x, y, 4)
        buttons = pew.keys()
        while pew.keys():
            pew.tick(delay)
        dx = 0
        dy = 0
        if buttons & pew.K_UP:
            dy = -1
        elif buttons & pew.K_DOWN:
            dy = 1
        elif buttons & pew.K_LEFT:
            dx = -1
        elif buttons & pew.K_RIGHT:
            dx = 1
        if (0 <= x + dx <= 7 and 0 <= y + dy <= 7 and
                world.pixel(x + dx, y + dy) != 2):
            world.pixel(x, y, 0)
            x += dx
            y += dy
            world.pixel(x, y, 4)
        elif (dy == 0 and 1 <= x + dx <= 6 and
                world.pixel(x + 2 * dx, y + 2 * dy) == 0):
            world.pixel(x, y, 0)
            x += dx
            y += dy
            world.pixel(x, y, 4)
            world.pixel(x + dx, y + dy, 2)
        gems = 0
        for row in range(7, -1, -1):
            for col in range(8):
                if world.pixel(col, row) == 3:
                    gems += 1
                elif world.pixel(col, row) == 2:
                    if world.pixel(col, row + 1) == 0:
                        world.pixel(col, row, 0)
                        world.pixel(col, row + 1, 2)
                        if world.pixel(col, row + 2) == 4:
                            end = True
                    elif world.pixel(col, row + 1) in {2, 3}:
                        if (world.pixel(col + 1, row) == 0 and
                           world.pixel(col + 1, row + 1) == 0):
                                world.pixel(col, row, 0)
                                world.pixel(col + 1, row, 2)
                        elif (world.pixel(col - 1, row) == 0 and
                           world.pixel(col - 1, row + 1) == 0):
                                world.pixel(col, row, 0)
                                world.pixel(col - 1, row, 2)
        if gems == 0:
            end = True
        world.pixel(x, y, 3 if blink else 0)
        pew.show(world)
        pew.tick(delay)
        blink = not blink

    import supervisor
    supervisor.reload()

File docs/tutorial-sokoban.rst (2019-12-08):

Sokoban Tutorial
****************

When looking for simple games to implement on PewPew, it helps to look back to
the times when computers were so young and underpowered, compared to today, that
simple games were all they could run. One of those games is Sokoban. Let’s try
to write a Sokoban for PewPew!

`Sokoban <https://en.wikipedia.org/wiki/Sokoban>`_ is a puzzle game where you
play a warehouse worker who has to push packing crates around until they are
where they are supposed to be, which is indicated by marks on the floor.
Unfortunately, your warehouse is a bit labyrinthine, and you can only push the
crates, not pull them, so you need to plan carefully: if you push a crate into a
corner, you can never get it back out.

As in the :doc:`tutorial`, create a file named *code.py* containing the basic
setup and game loop. Instead of a blank screen, we put the game board on the
screen right away: some walls, indicated by color 1 (dim or green), surrounding
free space of color 0 (black). ::

    import pew

    pew.init()
    screen = pew.Pix.from_iter((
        (1, 1, 1, 1, 1, 1, 1, 1),
        (1, 0, 0, 0, 0, 0, 0, 1),
        (1, 0, 0, 0, 0, 0, 0, 1),
        (1, 0, 0, 0, 0, 0, 0, 1),
        (1, 0, 0, 0, 0, 0, 0, 1),
        (1, 0, 0, 0, 0, 0, 0, 1),
        (1, 0, 0, 0, 0, 0, 0, 1),
        (1, 1, 1, 1, 1, 1, 1, 1),
    ))

    while True:
        keys = pew.keys()

        pew.show(screen)
        pew.tick(1/6)

Let’s add a player character, indicated by a bright pixel, that can be moved
around with the directional keys. We erase the pixel in the old position at the
beginning of the loop by replacing it with 0 (black floor), then move the
position if any keys are pressed, and finally paint it at the new position:

.. code-block:: python
    :emphasize-lines: 5,6,9,11-19

    ...
        (1, 1, 1, 1, 1, 1, 1, 1),
    ))

    x = 4
    y = 1

    while True:
        screen.pixel(x, y, 0)
        keys = pew.keys()
        if keys & pew.K_UP:
            y -= 1
        elif keys & pew.K_DOWN:
            y += 1
        elif keys & pew.K_LEFT:
            x -= 1
        elif keys & pew.K_RIGHT:
            x += 1
        screen.pixel(x, y, 3)
        pew.show(screen)
        pew.tick(1/6)

Note that we use ``elif`` (Python’s shorthand for “else, if”) to check for
different keys, which means that we can only move in one of the four directions
at once. If we used ``if`` for every key, we could move e.g. right and down at
the same time, that is, move diagonally. (We could also move up and down at the
same time, which means not moving at all.) For Sokoban, we don’t want to be able
to move diagonally, only horizontally and vertically, so we use ``elif``.

If you try this, you will notice that the player can move through walls and
outside of the screen, leaving holes in the walls. Let’s fix that.

Instead of moving right away when a key is pressed, we first record in what
direction we want to move in the variables ``dx`` and ``dy`` (the ``d`` stands
for “delta” or “difference”, because this is going to be the difference between
the new and old position). Then we look ahead what is in that direction, the
``target`` pixel, and only move when it is “floor” (0).

.. code-block:: python
    :emphasize-lines: 5,6,8,10,12,14-18

    ...
    while True:
        screen.pixel(x, y, 0)
        keys = pew.keys()
        dx = 0
        dy = 0
        if keys & pew.K_UP:
            dy = -1
        elif keys & pew.K_DOWN:
            dy = 1
        elif keys & pew.K_LEFT:
            dx = -1
        elif keys & pew.K_RIGHT:
            dx = 1
        target = screen.pixel(x+dx, y+dy)
        if target == 0:
            x += dx
            y += dy
        screen.pixel(x, y, 3)
        pew.show(screen)
        pew.tick(1/6)

Now that that works as it should, let’s add the next element, a crate,
represented by a bright pixel (3):

.. code-block:: python
    :emphasize-lines: 6

    ...
        (1, 1, 1, 1, 1, 1, 1, 1),
        (1, 0, 0, 0, 0, 0, 0, 1),
        (1, 0, 0, 0, 0, 0, 0, 1),
        (1, 0, 0, 0, 0, 0, 0, 1),
        (1, 0, 0, 3, 0, 0, 0, 1),
        (1, 0, 0, 0, 0, 0, 0, 1),
        (1, 0, 0, 0, 0, 0, 0, 1),
        (1, 1, 1, 1, 1, 1, 1, 1),
    ...

When a crate is in front of a player wanting to move, it will be pushed away one
pixel further in the same direction, and the player can move:

.. code-block:: python
    :emphasize-lines: 5-8

    ...
        if target == 0:
            x += dx
            y += dy
        elif target == 3:
            screen.pixel(x+dx+dx, y+dy+dy, 3)
            x += dx
            y += dy
        screen.pixel(x, y, 3)
        pew.show(screen)
        pew.tick(1/6)

There is no need to erase the crate at its old position, because it will
immediately be overwritten with the player anyway.

Test it and you will notice that you can push the crate through walls, punching
holes in the walls again. We obviously need to check what’s *behind* the crate
first, before we decide to move it.

.. code-block:: python
    :emphasize-lines: 3,7

    ...
        target = screen.pixel(x+dx, y+dy)
        behind = screen.pixel(x+dx+dx, y+dy+dy)
        if target == 0:
            x += dx
            y += dy
        elif target == 3 and behind == 0:
            screen.pixel(x+dx+dx, y+dy+dy, 3)
            x += dx
            y += dy
    ...

That works, but we now have two bright pixels on the screen, the player and the
crate, and when the player isn’t moving, you can’t tell which is which. We still
have an unused color available that we could use for one of them, 2 (medium
brightness or red), but we’d like to use that for the marks on the floor later.
Instead, let’s make the player blink. That needs another variable to keep track
of what the last state was, which is then reversed after every time the player
is drawn. A natural choice for such a variable with two states is a boolean with
its two values ``True`` and ``False``.

.. code-block:: python
    :emphasize-lines: 4

    ...
    x = 4
    y = 1
    blink = True

    while True:
    ...

.. code-block:: python
    :emphasize-lines: 3,4

    ...
            y += dy
        screen.pixel(x, y, 3 if blink else 2)
        blink = not blink
        pew.show(screen)
        pew.tick(1/6)

Time for the last missing element: the marks on the floor. We represent them by
color 2:

.. code-block:: python
    :emphasize-lines: 6

    ...
        (1, 1, 1, 1, 1, 1, 1, 1),
        (1, 0, 0, 0, 0, 0, 0, 1),
        (1, 0, 0, 0, 0, 0, 0, 1),
        (1, 0, 0, 0, 0, 0, 0, 1),
        (1, 0, 0, 3, 0, 2, 0, 1),
        (1, 0, 0, 0, 0, 0, 0, 1),
        (1, 0, 0, 0, 0, 0, 0, 1),
        (1, 1, 1, 1, 1, 1, 1, 1),
    ...

And the player and crates can move over them just like over bare floor:

.. code-block:: python
    :emphasize-lines: 3,6

    ...
        behind = screen.pixel(x+dx+dx, y+dy+dy)
        if target in {0, 2}:
            x += dx
            y += dy
        elif target == 3 and behind in {0, 2}:
            screen.pixel(x+dx+dx, y+dy+dy, 3)
            x += dx
            y += dy
    ...

Try it out, and you will find the next problem: the mark is erased by either
player or crate moving over it. This is because when overwriting the respective
pixel with 2 or 3 to draw the player, we lose the information whether there was
a mark there, and in the first line of the next loop, we will restore bare floor
(0) even when there should have been a mark (2). We somehow need to preserve
this information.

To solve this, there is a trick we can use. So far, we have always used pixel
values 0–3 for black, dim, medium, bright or black, green, red, orange. These
are all the colors that our hardware can display. But what happens if we use
higher numbers? If you try it, you will find that 4 produces black, 5 produces
dim/green again, 6 medium/red, 7 bright/orange, 8 black, and so on – the pattern
just repeats every four steps. In other words, you can add 4 to a pixel value
without changing its apparent color.

We can use this to our advantage: If we represent a crate-on-bare-floor as 3 and
a crate-on-mark as 7, they will both look the same, but we can still distinguish
them in the code. The same goes for the player: if the pixel blinks between 2
and 3, it’s on bare floor, if it blinks between 6 and 7, it’s on a mark.

For the player, this needs to be applied on the line where we erase the player
and restore the floor (with or without mark), and on the line where we draw the
new player over the previous floor or crate (each with or without mark):

.. code-block:: python
    :emphasize-lines: 3

    ...
    while True:
        screen.pixel(x, y, 0 if screen.pixel(x, y) < 4 else 2)
        keys = pew.keys()
    ...

.. code-block:: python
    :emphasize-lines: 3

    ...
            y += dy
        screen.pixel(x, y, (3 if blink else 2) + (4 if screen.pixel(x, y) in {2, 7} else 0))
        blink = not blink
    ...

For the crate, it needs to be applied on the line where we detect a crate in
front of the player and on the line where we draw the new crate over the
previous floor:

.. code-block:: python
    :emphasize-lines: 5,6

    ...
        if target in {0, 2}:
            x += dx
            y += dy
        elif target in {3, 7} and behind in {0, 2}:
            screen.pixel(x+dx+dx, y+dy+dy, 3 if behind == 0 else 7)
            x += dx
            y += dy
    ...

Test this and check that you can now both walk over the mark and push the crate
over the mark without erasing it. Congratulations – with this, our game
mechanics are now complete! The game still does not detect when all crates are
placed on their marks and therefore the level is solved, though. Let’s add that.

The easiest way of checking that is to count all bare marks: if none of them are
left, the puzzle is solved. So, iterate over all pixels (with an outer loop over
all rows and an inner loop over the pixels of each row) and count up every time
you see a bare mark. If the count remains 0, break out of the top-level ``while
True`` loop, at which point the program ends because there’s no more code after
the loop. It’s important to do this before we draw the player, who might stand
on a mark and thereby hide it from the counting otherwise.

.. code-block:: python
    :emphasize-lines: 6-12

    ...
        elif target in {3, 7} and behind in {0, 2}:
            screen.pixel(x+dx+dx, y+dy+dy, 3 if behind == 0 else 7)
            x += dx
            y += dy
        count = 0
        for b in range(8):
            for a in range(8):
                if screen.pixel(a, b) == 2:
                    count += 1
        if count == 0:
            break
        screen.pixel(x, y, (3 if blink else 2) + (4 if screen.pixel(x, y) in {2, 7} else 0))
        blink = not blink
        pew.show(screen)
        pew.tick(1/6)

You can test this, but testing it with only one crate is not a very general
test, so add another one, and a mark for it.

.. code-block:: python
    :emphasize-lines: 4,7

    ...
        (1, 1, 1, 1, 1, 1, 1, 1),
        (1, 0, 0, 0, 0, 0, 0, 1),
        (1, 0, 3, 0, 0, 0, 0, 1),
        (1, 0, 0, 0, 0, 0, 0, 1),
        (1, 0, 0, 3, 0, 2, 0, 1),
        (1, 0, 2, 0, 0, 0, 0, 1),
        (1, 0, 0, 0, 0, 0, 0, 1),
        (1, 1, 1, 1, 1, 1, 1, 1),
    ...

After you verify that the completion detection works properly – the game exits
when both crates are on their marks, no earlier and no later – it’s now up to
you to make the game more interesting by adding more walls to the level. Or
maybe you want to extend the game to support multiple levels of increasing
difficulty? Or add a nice reward animation for a completed level? Have fun!

Here is the complete code in its final state again::

    import pew

    pew.init()
    screen = pew.Pix.from_iter((
        (1, 1, 1, 1, 1, 1, 1, 1),
        (1, 0, 0, 0, 0, 0, 0, 1),
        (1, 1, 3, 1, 0, 0, 0, 1),
        (1, 0, 0, 1, 0, 1, 1, 1),
        (1, 0, 0, 3, 0, 2, 0, 1),
        (1, 0, 2, 1, 0, 1, 0, 1),
        (1, 0, 0, 0, 0, 1, 0, 1),
        (1, 1, 1, 1, 1, 1, 1, 1),
    ))

    x = 4
    y = 1
    blink = True

    while True:
        screen.pixel(x, y, 0 if screen.pixel(x, y) < 4 else 2)
        keys = pew.keys()
        dx = 0
        dy = 0
        if keys & pew.K_UP:
            dy = -1
        elif keys & pew.K_DOWN:
            dy = 1
        elif keys & pew.K_LEFT:
            dx = -1
        elif keys & pew.K_RIGHT:
            dx = 1
        target = screen.pixel(x+dx, y+dy)
        behind = screen.pixel(x+dx+dx, y+dy+dy)
        if target in {0, 2}:
            x += dx
            y += dy
        elif target in {3, 7} and behind in {0, 2}:
            screen.pixel(x+dx+dx, y+dy+dy, 3 if behind == 0 else 7)
            x += dx
            y += dy
        count = 0
        for b in range(8):
            for a in range(8):
                if screen.pixel(a, b) == 2:
                    count += 1
        if count == 0:
            break
        screen.pixel(x, y, (3 if blink else 2) + (4 if screen.pixel(x, y) in {2, 7} else 0))
        blink = not blink
        pew.show(screen)
        pew.tick(1/6)

You can also find this at https://github.com/pewpew-game/game-sokoban.

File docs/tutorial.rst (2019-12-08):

Bouncing Ball Tutorial
**********************

Let's try to write a simple bouncing ball demo, where a single pixel moves
around the screen and bounces off its edges. This will let us get familiar
with the library.

Start by creating a file called "code.py" --- that is where all our code
will go. As long as such a file exists, PewPew will try to run it on startup
and on reset. Later, when you finish working on your game, you can rename it
to whatever you call your game, and then PewPew will fall back to running
"main.py", which contains the game selection menu.

To use the PewPew library, we need to first import it into our code. So we need to start with this line::

    import pew

Then we need to tell the library to switch the display on and generally prepare
everything for displaying our ball. We do that by calling the ``init`` function
like this::

    import pew

    pew.init()

We will want our demo program to run all the time in a loop, so we will need an
infinite loop. We can limit the loop's speed to run 12 times a second, which is
slow enough to see the movements, but not too slow::

    import pew

    pew.init()
    while True:
        pew.tick(1/12)

Now, we will need an image that we will display on the screen. In PewPew,
images are represented as ``Pix`` objects. So we can create an empty image the
size of the display, and display it in our loop::

    import pew

    pew.init()
    screen = pew.Pix()
    while True:
        pew.show(screen)
        pew.tick(1/12)

Now we will add our pixel. We will make it start at coordinates ``0, 0``, and
we will draw it with color ``3``, which is the brightest::

    import pew

    pew.init()
    screen = pew.Pix()
    x = 0
    y = 0
    while True:
        screen.pixel(x, y, 3)
        pew.show(screen)
        pew.tick(1/12)

Now let's make the pixel actually move::

    import pew

    pew.init()
    screen = pew.Pix()
    x = 0
    y = 0
    dx = 1
    dy = 1
    while True:
        x += dx
        y += dy
        screen.pixel(x, y, 3)
        pew.show(screen)
        pew.tick(1/12)

After running this, you will see a diagonal line on the display. That's because
the old positions of the pixel are not getting deleted. And the pixel
keeps on going forever outside the screen. We can fix that. Let's start by
deleting the old position::

    import pew

    pew.init()
    screen = pew.Pix()
    x = 0
    y = 0
    dx = 1
    dy = 1
    while True:
        screen.pixel(x, y, 0)
        x += dx
        y += dy
        screen.pixel(x, y, 3)
        pew.show(screen)
        pew.tick(1/12)

We simply draw a black pixel at the old position before drawing a bright one at
the new one. Since we only update the screen once a frame, those two operations
are visible at the same time. Now, let's make the pixel bounce off the edges::

    import pew

    pew.init()
    screen = pew.Pix()
    x = 1
    y = 1
    dx = 1
    dy = 1
    while True:
        screen.pixel(x, y, 0)
        if not 0 < x < 7:
            dx = -dx
        if not 0 < y < 7:
            dy = -dy
        x += dx
        y += dy
        screen.pixel(x, y, 3)
        pew.show(screen)
        pew.tick(1/12)

We had to move our starting point a bit, because otherwise it will get stuck in
the corner. Now you should see our pixel going from one corner to the other.
That's neat, but a little bit boring. Maybe if we changed the starting position
it would be better::

    import pew

    pew.init()
    screen = pew.Pix()
    x = 3
    y = 1
    dx = 1
    dy = 1
    while True:
        screen.pixel(x, y, 0)
        if not 0 < x < 7:
            dx = -dx
        if not 0 < y < 7:
            dy = -dy
        x += dx
        y += dy
        screen.pixel(x, y, 3)
        pew.show(screen)
        pew.tick(1/12)

Maybe we could affect the ball's behavior with the buttons? For instance,
pressing `O` could make it bounce horizontally, and pressing `X` vertically::

    import pew

    pew.init()
    screen = pew.Pix()
    x = 3
    y = 1
    dx = 1
    dy = 1
    while True:
        keys = pew.keys()
        screen.pixel(x, y, 0)
        if not 0 < x < 7 or keys & pew.K_O:
            dx = -dx
        if not 0 < y < 7 or keys & pew.K_X:
            dy = -dy
        x += dx
        y += dy
        screen.pixel(x, y, 3)
        pew.show(screen)
        pew.tick(1/12)

Could we have a nicer background than just black? Let's try a check board::

    import pew

    pew.init()
    screen = pew.Pix()
    background = pew.Pix.from_iter((
        (1, 0, 1, 0, 1, 0, 1, 0),
        (0, 1, 0, 1, 0, 1, 0, 1),
        (1, 0, 1, 0, 1, 0, 1, 0),
        (0, 1, 0, 1, 0, 1, 0, 1),
        (1, 0, 1, 0, 1, 0, 1, 0),
        (0, 1, 0, 1, 0, 1, 0, 1),
        (1, 0, 1, 0, 1, 0, 1, 0),
        (0, 1, 0, 1, 0, 1, 0, 1),
    ))
    x = 3
    y = 1
    dx = 1
    dy = 1
    while True:
        keys = pew.keys()
        screen.blit(background)
        if not 0 < x < 7 or keys & pew.K_O:
            dx = -dx
        if not 0 < y < 7 or keys & pew.K_X:
            dy = -dy
        x += dx
        y += dy
        screen.pixel(x, y, 3)
        pew.show(screen)
        pew.tick(1/12)

Instead of deleting our pixel with a black pixel, we simply copy the whole
background all over the screen, and then draw our pixel in the new position.

How about making the ball larger::

    import pew

    pew.init()
    screen = pew.Pix()
    ball = pew.Pix.from_iter((
        (3, 2),
        (2, 1),
    ))
    background = pew.Pix.from_iter((
        (1, 0, 1, 0, 1, 0, 1, 0),
        (0, 1, 0, 1, 0, 1, 0, 1),
        (1, 0, 1, 0, 1, 0, 1, 0),
        (0, 1, 0, 1, 0, 1, 0, 1),
        (1, 0, 1, 0, 1, 0, 1, 0),
        (0, 1, 0, 1, 0, 1, 0, 1),
        (1, 0, 1, 0, 1, 0, 1, 0),
        (0, 1, 0, 1, 0, 1, 0, 1),
    ))
    x = 3
    y = 1
    dx = 1
    dy = 1
    while True:
        keys = pew.keys()
        screen.blit(background)
        if not 0 < x < 6 or keys & pew.K_O:
            dx = -dx
        if not 0 < y < 6 or keys & pew.K_X:
            dy = -dy
        x += dx
        y += dy
        screen.blit(ball, x, y)
        pew.show(screen)
        pew.tick(1/12)

We had to adjust the boundaries of the screen for the larger ball here.

Now experiment with this code yourself and see what you can make.

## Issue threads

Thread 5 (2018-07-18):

Disabling tick()’s catch-up behavior

cwalther, 2018-07-18:
The `pew.tick(delay)` function currently acts like “Add a tick on the time scale _delay_ after the last one, and if that’s in the future, wait for it. The first tick is always at the time `pew.init()` was called.”. This has the effect of striving for the desired average frame rate on the long run: when several frames have taken longer than _delay_, or one frame has taken several times _delay_, so that the ticks have slipped into the past, it accelerates the frame rate by making `tick()` return immediately as many times as needed to catch up to the desired overall number of frames.

Usually this is useful, desirable behavior. There are cases where it is not, however: when deliberately running a long computation during which no user input or regular screen updates are needed, then resuming regular updates. Specifically, I am writing a player-vs.-computer Othello game: When it is the player’s turn, regular keyboard/screen updates are needed to move a cursor on the board. `tick` is used to get a constant update rate during that time. When it’s the computer’s turn and the AI is thinking, user input should be ignored and no screen updates are needed. `tick` is not called for several seconds during this time. With the current implementation, this means that when the AI is done thinking and control returns to the player, the catch-up behavior kicks in and the cursor blinks and moves very fast for a few seconds, then settles down to its normal rate. I would like to avoid this and somehow tell the library that the thinking time was spent deliberately and it should not try to catch up with the frames it “missed” during that time.

I could do that by measuring how long the long-running computation took and passing that as the argument to the next `tick`, but that feels like a complicated, dirty workaround. This can be solved more cleanly inside the library.

One way of achieving this that I can think of is to
1. modify the `tick` function to act like “Add a tick on the time scale _delay_ after the last one, and if that’s in the future, wait for it. If there is no last tick, add one now (and don’t wait, since _now_ is not in the future).”
2. add a “reset“ function to “clear all existing ticks” (I call it `tock` but I don’t insist on that name).

The game would then call `tock()` before or after the long-running operation, so that the first `tick(delay)` after resuming regular updates would start a new sequence of regular ticks. Specified as above, that first `tick` would not wait. One could also argue that it should wait for _delay_. But depending on how much CPU time computing a frame takes, both may be equally wrong, and waiting for zero seems like the lesser evil to me.

The implementation could look like this:
```python
def tick(delay):
    global _tick
    if _tick is None:
        _tick = time.monotonic()
    else:
        _tick += delay
        time.sleep(max(0, _tick - time.monotonic()))

def tock():
    global _tick
    _tick = None
```

Rather than by a separate `tock` function, the “reset” behavior could also be triggered by a special argument to `tick`, such as `tick()` or `tick(-1)` or `tick(delay, reset=True)`.

Alternatively, one could specify that `tick` should catch up at most once, i.e. the backlog of “missed“ frames would be clamped to one, by never setting new ticks in the past. That would however lose the property of keeping to a long-term average frame rate.

Rather than submit any of this as a pull request right away, I would like to discuss it first. Do you agree that this is a problem? One that is worth spending some bytes of library code on? Can you think of any better solution?

deshipu, 2018-07-18:
Hi, I'm sorry that I will be brief, I will give you better replies tomorrow (and to your pull requests too). I really appreciate you taking the time to work on this, and doing such deep analysis. I'm afraid you are assuming more foresight on my part than I deserve — that behavior of the `tick()` function is pretty much accidental, it was simply easy to write it that way. I think that once you skip more than one frame, all bets are off. Most likely then your update code is slower than the desired framerate, and it will only get worse with time. I think the sanest thing to do is to only allow it to skip one frame, and not let the error accumulate. That would be the least surprising behavior, and the most useful for such simple games — at least for the use cases that I can imagine. And if your game has some special needs, you can always write your own tick function — it's there only for convenience after all. What do you think?

cwalther, 2018-07-19:
You’re right, now that I think about it a bit more, the usefulness of a constant long-term frame rate is marginal for typical PewPew games. The example I subconsciously had in mind involved physics simulation in a multiplayer online game, which is probably not something beginners are going to do here. :) So, an implementation of the behavior you suggest could be
```python
def tick(delay):
    global _tick
    now = time.monotonic()
    _tick = max(_tick + delay, now)
    time.sleep(max(0, _tick - now))
```
and that works fine for my purpose.

deshipu, 2018-07-19:
Do you want to make a pull request, or should I do it?

Closed 2018-07-20.

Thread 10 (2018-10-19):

Port to MicroPython

cwalther, 2018-10-19:
At [cwalther/pewpew:master-micropy](https://github.com/cwalther/pewpew/compare/master-micropy), I have ported the PewPewLite4.0 library and the games from CircuitPython to MicroPython. I am not asking that this be integrated into the main repository, so this is not a pull request (though I wouldn’t oppose either). I merely want to bring it to the attention of people who might have a use for it. I mainly did it for myself, for the following reasons:
- I was getting weird errors with one complex program and wanted to check if they also occur with MicroPython (they don’t).
- I wanted to play with asyncio, which is not available on CircuitPython yet.
- I needed umqtt, which is not built-in on CircuitPython and does not run without adjustments.

Main differences that required porting are
- `time` API: `monotonic()` is unavailable, and integer milliseconds are preferred over floating-point seconds.
- `machine.I2C.writeto()` has no `end` argument, which requires a separate 1-byte buffer.

Tested on ESP8266 (Adafruit Feather HUZZAH). I don’t even know if there are any other Feather boards that run MicroPython. If so, I’m not sure if the I2C pin assignments are universal. Contributions welcome.

deshipu, 2018-10-19:
This is awesome! I definitely want to have a MicroPython version, especially since there is also an ESP32 Feather that doesn't have CircuitPython support at all. I will look in the morning and try to integrate it with the current repository structure somehow.

deshipu, 2018-10-19:
By the way, it would be interesting to see the program that is giving you the problems.

cwalther, 2018-10-20:
Cool! Options for integrating it could be
- A separate branch that mirrors everything, as I did here. That makes it easy to compare the two versions and keep them synchronized, but is maybe a little less discoverable.
- Separate subdirectories under _libs/_. That requires that everything outside of that runs on both, which makes the code a little larger. This is already achieved for the two games included here, which fortunately only required catching ImportErrors (_frog.py_ even works unmodified), and I also have it working for the menu module from #9, but there it adds a few more lines to abstract the `time` API differences.

I didn’t know about the ESP32 Feather not having CircuitPython. By the way, have you talked to the https://www.oxocard.ch guys at Maker Faire Zürich? It has an 8x8 screen, six buttons, and an ESP32 running MicroPython – perfect platform to run PewPew on! 😀 I didn’t buy one because I had already bought the first (ATmega) version a year ago and never did anything with it.

The problematic program was a WIP experiment that I didn’t plan to publish (yet), but I’ll think about it. The symptom was that I occasionally got exceptions because some variables were `None` or some object attributes were missing that could not possibly be `None` or missing according to my code. Very strange. The program was so large (about 6 KB) that it didn’t compile on the device anymore, I had to precompile it, and it made excessive use of generators for animation – I suspect it was either of these that caused the problem. But I never tried to get a minimal reproducing example and make a proper bug report.

deshipu, 2018-10-20:
I need to reorganize the repositories a little, than every platform can get its own repository, forked from the same common parent, so that it will be easy to do comparisons and pulls between them. I think that is the only sane approach. Unfortunately, I'm right now pretty busy with the Hacakday Prize stuff (deadline on Monday) and then the PyCon.de (until the end of the week). Hopefully I can work on this after that.

I really want to have all the ports code-compatible, so that there is no modification of programs necessary. If that means including additional modules just because the original had them called differently, so be it. I will work on that once it's in its own repo.

I talked to the oxocard people briefly, but I didn't really show them PewPew. I think they are going in a slightly different direction than me, and that it's not a compatible platform from the point of view of controls (no d-pad, etc.).

cwalther, 2018-10-20:
No hurry from my part. Good luck with the Hackaday Prize and enjoy PyCon!

By “include additional modules”, do you mean that the MicroPython port would include e.g. a `time` module that offers `monotonic()` and a `random` module aliasing `urandom`, so that the existing games in this repository would work unmodified? But other existing games written for CircuitPython could be using all kinds of CircuitPython APIs that are not available in MicroPython, so where would you stop? I see no better solution here than to leave it up to the game author to make their game run on both, if they want it to be cross-platform.

deshipu, 2018-10-22:
Well, I would limit it to the modules that are built into CircuitPython and are not for interacting with hardware  (which would open a completely new can of worms). For now I'm thinking about `time`, `random` and `microcontroller` (for resetting the board).

deshipu, 2019-03-02:
I just went ahead and created the separate repositories for different version of the pew library. I can also create one for MicroPython now, if you are still interested?

cwalther, 2019-03-02:
Sure! It seems like the choice between CircuitPython and MicroPython is partly orthogonal to the choice of platform, so at this point there would be pew-pewpewlite-4.x-micropython and pew-d1mini-micropython? (I can’t contribute the latter because I don’t currently have a PewPew D1 Mini. But then it looks a bit unmaintained, comparing it to pewpewlite-4.x I can spot several bugs that indicate nobody has been using it.)

I always find it a bit of a shame when repository reorganizations lose the existing history, but maybe in this case it wasn’t worth the effort.

deshipu, 2019-03-02:
The d1mini already uses MicroPython, actually. It's for an early prototype that I made using it, which I kept because I have given a few units to some people. Indeed it is not maintained.

I could have kept the history by cloning the repository and just removing all the other files, and maybe stripping the history of those files as well, but it's more work than I have time for right now. The original repository is still there, so the history is not completely lost.

I will create ``pew-pewpewlite-4.x-micropython`` then.

cwalther, 2019-03-03:
I have pushed my stuff there. I noticed that the pew-* repositories are not forks of each other, which seems to mean that GitHub cannot compare between them, do you think that’s a problem?

deshipu, 2019-03-03:
Thank you. I can't fork a repository to the same account, so I have no idea how I would make them forks for github. In any case, git lets you do operations on unrelated repositories anyways, so it should all be good.

deshipu, 2019-03-03:
You probably want to edit the license file to include yourself in it.

cwalther, 2019-03-03:
> I can't fork a repository to the same account

Hmm, you’re right. Weird. That seems like a completely needless restriction.

> You probably want to edit the license file to include yourself in it.

I didn’t do that because in this case I consider my contributions minor enough that I’m fine with assigning copyright to you. But if you prefer to have all contributors mentioned, sure, I can do that.

deshipu, 2019-03-03:
> But if you prefer to have all contributors mentioned, sure, I can do that.
I think it's only fair.

cwalther, 2019-03-10:
I think we’re done here. Thanks!

Closed 2019-03-10.

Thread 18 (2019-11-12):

How to contribute documentation translations?

das-g, 2019-11-12:
For a workshop with Swiss pupils, who might not yet know English well enough to follow technical instructions in English, I'd like to translate at least the [bouncing ball tutorial](https://pewpew.readthedocs.io/en/latest/tutorial.html), probably also the [sokoban tutorial](https://pewpew.readthedocs.io/en/latest/tutorial-sokoban.html) and maybe even the complete PewPew documentation to German.

It probably would make sense for the results to show up https://pewpew.readthedocs.io/de and that German could be chosen in the documentation-version menu* for pages that have been translated.

*(This one: 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)

Where in the repo should I place the translated files to achieve that?

It would also probably make sense, that others can collaborate on the translations and that the same workflow is used for all target languages. For that, it'd be good to use a translation collaboration platform like Transifex or Crowdin. Is there any preference on which platform should be used for the PewPew documentation?

das-g, 2019-11-14:
I guess a workflow as suggested by https://www.sphinx-doc.org/en/master/usage/advanced/intl.html could work, but I'm unsure which files should be committed to the Git repository, and at what stage.

deshipu, 2019-11-21:
I'm sorry, I didn't see this issue. I know that @cwalther has already translated some of the PewPew documentation to German. I will make a clone of the repository with the docs, so that you can translate it.

deshipu, 2019-11-21:
I have created the ReadTheDocs project here: https://pewpew-german.readthedocs.io/
The repository is here: https://github.com/pewpew-game/pewpew-docs-de

Let me know your login at ReadTheDocs, then I can give you access to the settings.

das-g, 2019-11-21:
> Let me know your login at ReadTheDocs, then I can give you access to the settings.

I didn't have an account there yet, so I've created one now: [das-g](https://readthedocs.org/profiles/das-g/)

das-g, 2019-11-21:
> I have created the ReadTheDocs project here: https://pewpew-german.readthedocs.io/
> The repository is here: https://github.com/pewpew-game/pewpew-docs-de

That's a clone of https://github.com/pewpew-game/pewpew (+ commit https://github.com/pewpew-game/pewpew-docs-de/commit/d431d149ee5e042ca50e6c3f9306438db11bc358 to remove everything but the documentation), not a clone of @cwalther's existing translation, is it?

@cwalther, are your translations of (parts of) the PewPew documentation already available somewhere and if not, would you be willing to make them available?

cwalther, 2019-11-21:
I just pushed it here: https://github.com/cwalther/pewpew/commits/reference-de
It’s just that one commit 935bc91. I’ll look at what you
’re doing later, until tomorrow I’m busy.

das-g, 2019-11-21:
@deshipu Are you OK with me creating a Transifex organization for PewPew?

deshipu, 2019-11-21:
I don't see why not, as long as I don't have to pay for it.

deshipu, 2019-11-21:
However, I don't think transifex will give you something. CircuitPython itself already has German translation, you only need the documentation, and that's in text files, not gettext-like strings.

deshipu, 2019-11-21:
The way I usually do this is just translate and commit the text files, and then once in a while rebase with the original repository, to get any changes (they will show up as conflicts) and translate those.

I think we are set up now, so I'm going to close this issue.

das-g, 2019-11-21:
> I don't see why not, as long as I don't have to pay for it.

I assume PewPew would qualify as an OpenSource not-for-profit project for which they offer free plans.

> However, I don't think transifex will give you something. CircuitPython itself already has German translation, you only need the documentation, and that's in text files, not gettext-like strings.
>
> The way I usually do this is just translate and commit the text files, and then once in a while rebase with the original repository, to get any changes (they will show up as conflicts) and translate those.

The advantage of using a translation platform like Transifex or Crowdin even for prose is that during initial translation we can more easily see how much of the original has already be translated and what parts still need translation. This allows different phrases in the same document to be translated by different people without getting a giant mess, thus enabling us to split up the work.

Also, they enables us to have several translation suggestions for each phrase, without having to (ab)use the PR mechanism for choosing between them.

Further, I hope they enable people to update the translations who are not (yet) confident enough with Git to resolve merge conflicts. And again, if the documentations has multiple changed phrases, this allows to split up the work of updating them without having to leave Git conflict markers or similar inelegant stuff in committed documents.

The downside off course it that they're another tool to operate, and one I yet have to learn. (I know both platforms from the translators' perspective, but haven't yet managed own projects in them.)

> I think we are set up now, so I'm going to close this issue.

:+1:

das-g, 2019-12-07:
Update: Translation has started at https://www.transifex.com/pew-pew/pew-pew/

To generate upload the strings to be translated, I roughly followed https://www.sphinx-doc.org/en/master/usage/advanced/intl.html#using-transifex-service-for-team-translation. The steps are documented at [`pewpew-game/pewpew-docs-de` branch `german-translation-preparation`](https://github.com/pewpew-game/pewpew-docs-de/commits/german-translation-preparation) except for the `tx push -s` at the end, which doesn't have local effect.

If anyone wants to participate in translating or reviewing translations, please use the "Join team" button on the Transifex project.

Closed 2019-11-21.

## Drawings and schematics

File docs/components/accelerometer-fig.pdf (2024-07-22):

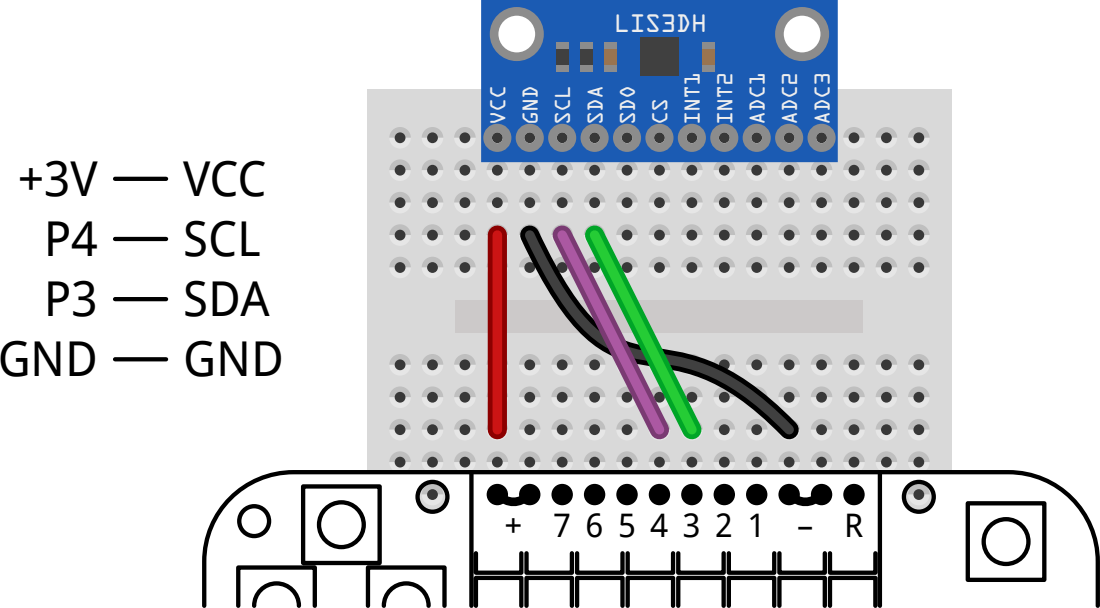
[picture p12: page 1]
LIS3DH; VCC; GND; SCL; SDA; SDO; INT1; INT2; ADC1; ADC2; ADC3; +3V P4 P3 GND; VCC SCL SDA GND

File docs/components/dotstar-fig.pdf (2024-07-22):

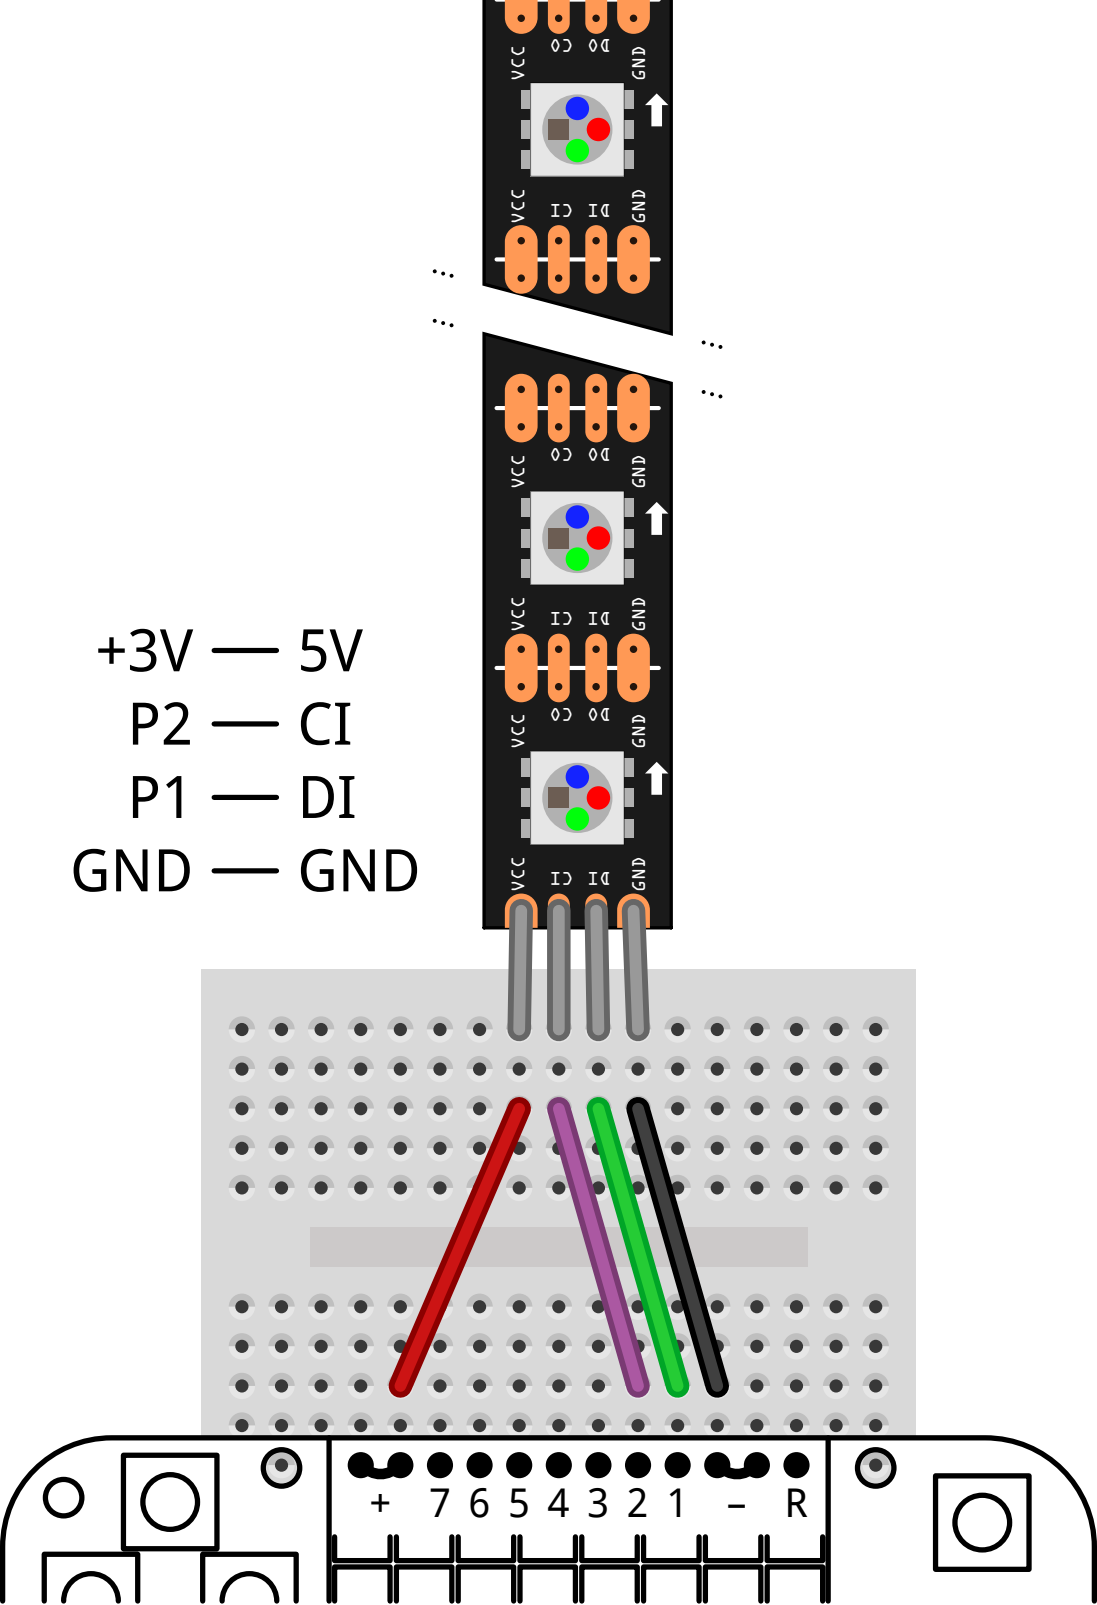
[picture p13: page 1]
+ 7 6 5 4 3 2 1 – R VCC; GNDCI; DI VCC; GND; VCC; GNDCIDI; +3V P2 P1 GND; 5V CI DI GND

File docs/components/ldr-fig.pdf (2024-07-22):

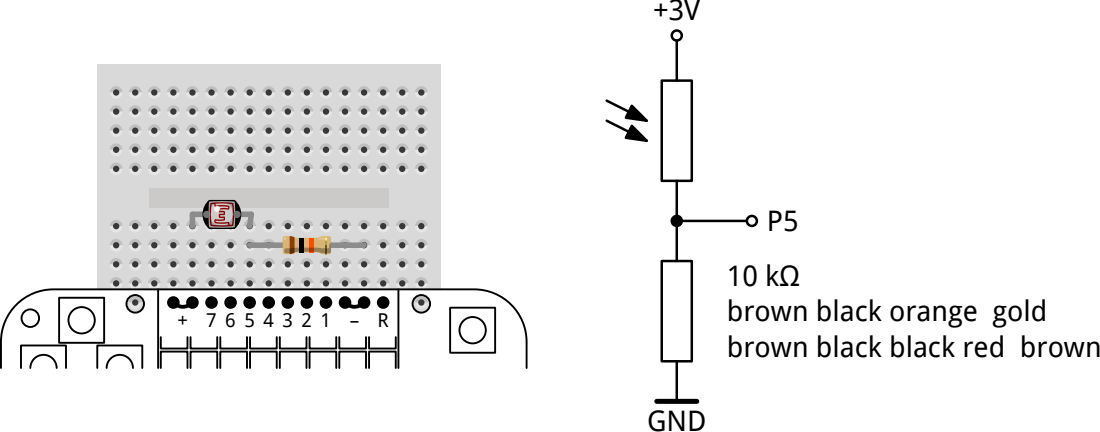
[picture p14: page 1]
GND

brown black orange gold
brown black black red brown

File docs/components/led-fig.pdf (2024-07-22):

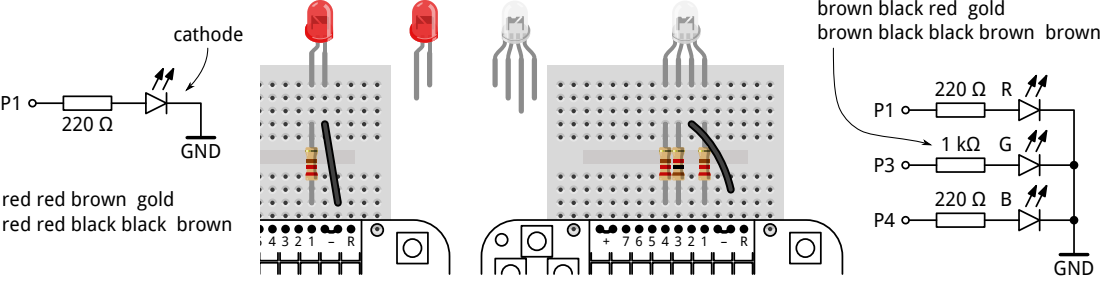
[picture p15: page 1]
GND; red red black black brown+ 7 6 5 4 3 2 1 – R; cathode

brown black red gold
brown black black brown brown

red red brown gold

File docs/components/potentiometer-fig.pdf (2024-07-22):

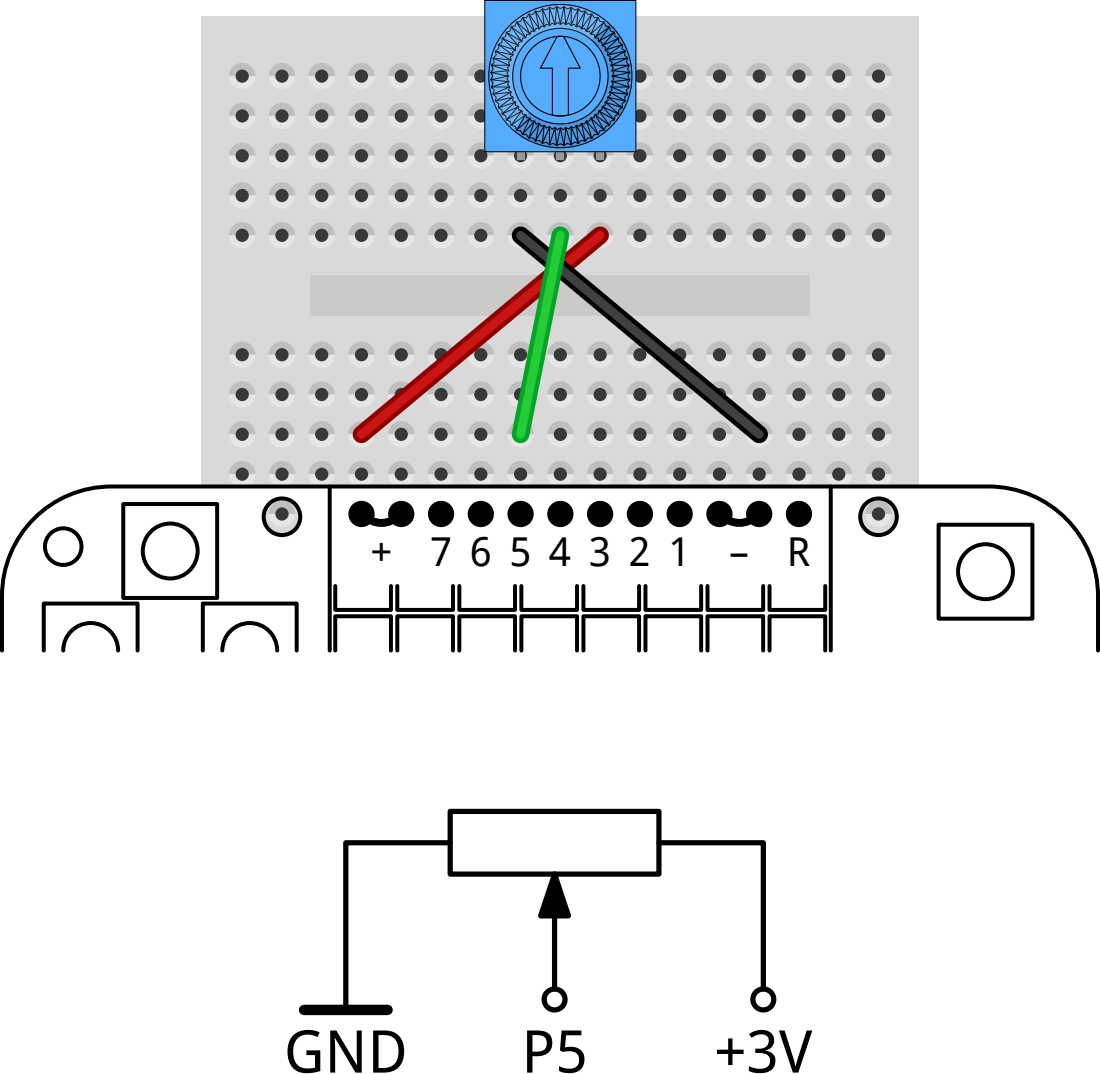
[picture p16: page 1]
GND

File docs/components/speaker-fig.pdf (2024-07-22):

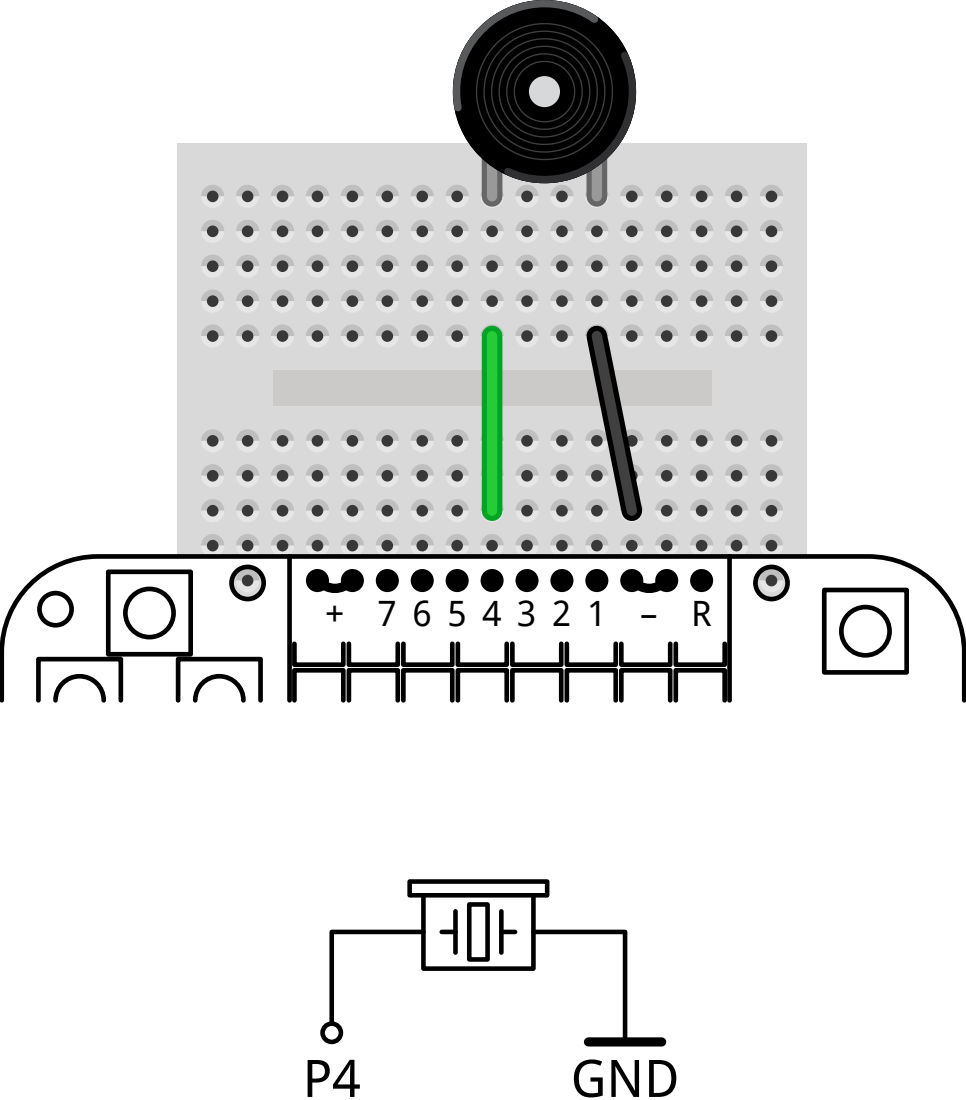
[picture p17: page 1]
GND

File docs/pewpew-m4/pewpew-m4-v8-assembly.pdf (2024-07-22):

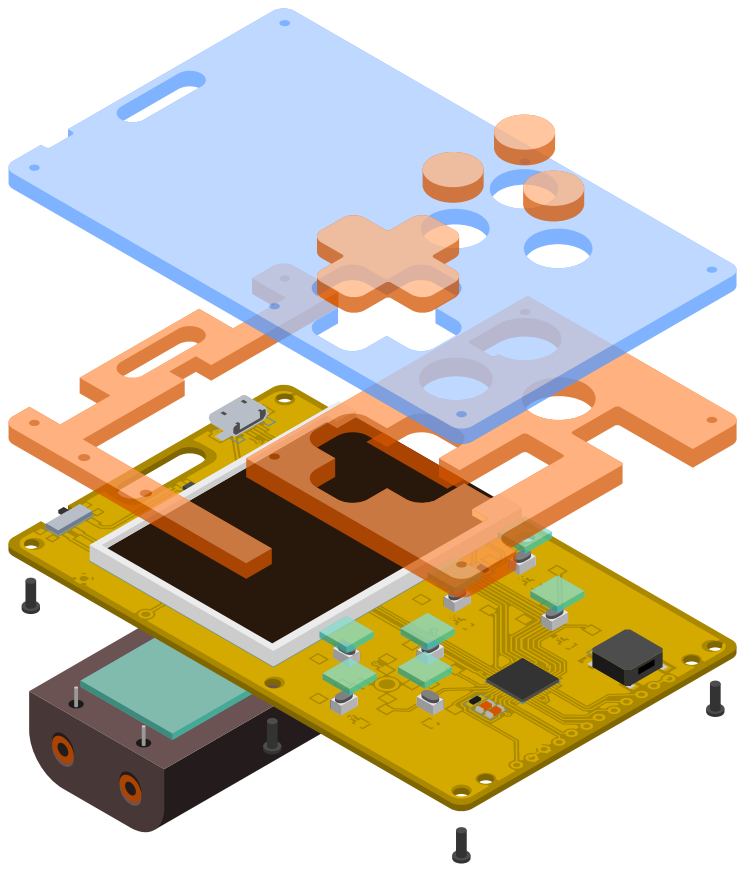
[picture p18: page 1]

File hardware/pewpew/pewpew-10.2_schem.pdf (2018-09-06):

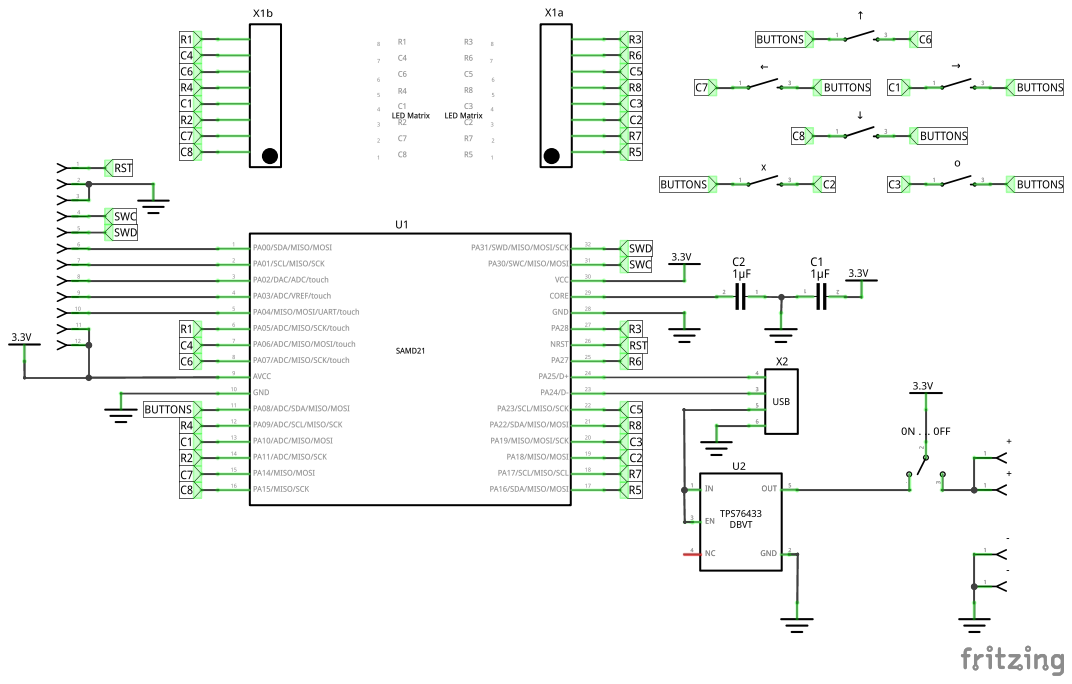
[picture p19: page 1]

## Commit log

2017-09-12 Add links to assembly instructions
2017-09-22 Fix no red in the rightmost column.
    The slice test assignment mistakenly enlarged _buffer from 17 to 18 bytes, and sending it all to the LED controller in show() would wrap around to the beginning of the framebuffer and overwrite its first byte with zero.
2017-09-22 CircuitPython 2.0.0 on ESP8266 does not appear to have a neopixel_write module.
    But since the Feather Huzzah does not have an onboard neopixel, we can probably just skip this.
    (There is a neopixel module with a neopixel_write function, but it's the one from MicroPython that takes a machine.Pin, not a digitalio.DigitalInOut.)
2017-10-19 Optimize the library code.
    [pewpewlite-4.0b.fz]
2018-06-16 Fix slots
2018-08-19 Make room for multiple PewPew devices
2018-09-06 Add hardware docs for PewPew Standalone
    [pewpew-10.2-bom.csv, pewpew-10.2.fz, pewpewlite-4.0b.fz]
2018-10-22 Add assembly instructions for PewPew 10.2
2018-10-27 Add docs on the connector
2018-10-27 Fix pin numbers in connector docs
2018-11-17 Put device list on a separate file
2018-11-17 Add photos to assembly instructions
2019-12-08 Add PewPew M4 to devices
2021-10-10 Fix latexpdf build.
    It doesn't understand SVGs - convert them to PDF, or those that Inkscape would mangle badly in the process to PNG. The html build will still prefer the SVGs.
    inkscape --export-type=pdf pewpew-m4/pewpew-m4-v8-2mm.svg pewpew-m4/pewpew-m4-v8-3mm.svg pewpew-m4/pewpew-m4-v8-assembly.svg
    inkscape --export-type=png --export-dpi=300 pewpew-m4/pewpew-m4-v8-pcb-bottom.svg pewpew-m4/pewpew-m4-v8-pcb-top.svg
    inkscape --export-type=png --export-dpi=600 pewpew-m4-v8-schematic.svg
2021-10-10 Fix sphinx-build warnings.
    WARNING: html_static_path entry '_static' does not exist
    We don't use it, so no need to mention it.
    WARNING: failed to reach any of the inventories (...) Not Found for url: https://circuitpython.readthedocs.io/en/stable/objects.inv
    There only seem to be "latest" and version-numbered versions at this time.
2021-10-11 Draft page on potentiometer/LDR.
    [ldr.fzz, potentiometer.fzz]
2021-10-11 LED page.
    [led.fzz]
2021-10-12 Addressable LED (dotstar) page.
    [dotstar.fzz]
2021-10-12 Piezo Speaker page.
    [speaker.fzz]
2021-10-13 LIS3DH accelerometer breakout drawing.
    Making a Fritzing component out of it is left as an exercise to the reader.
2021-10-13 Accelerometer page.
    [accelerometer.fzz]
2021-10-17 Adjust accelerometer address for the pseudo-LIS3DH we got.
2021-10-24 Update Sphinx to 3.x to see if that fixes the PDF build on Read the Docs.
    No significant changes noticed in the HTML output compared to 1.8.5 (previously used by RTD) and in the PDF output compared to 2.4.4 (previously used by me locally).
    Not updating all the way to the current version 4.x because that uses a different monospaced font in the PDF output, which disrupts the handout layout. Will try to fix that next.
